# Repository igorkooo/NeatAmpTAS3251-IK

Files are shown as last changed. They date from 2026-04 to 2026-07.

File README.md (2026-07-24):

# NeatAmpTAS3251 — 2×170W Class D Amplifier with I2S Input & DSP

> ⚠️ **Hobby project** — no deadlines, no warranties, no guarantees. Use at your own risk.

<p align="center">

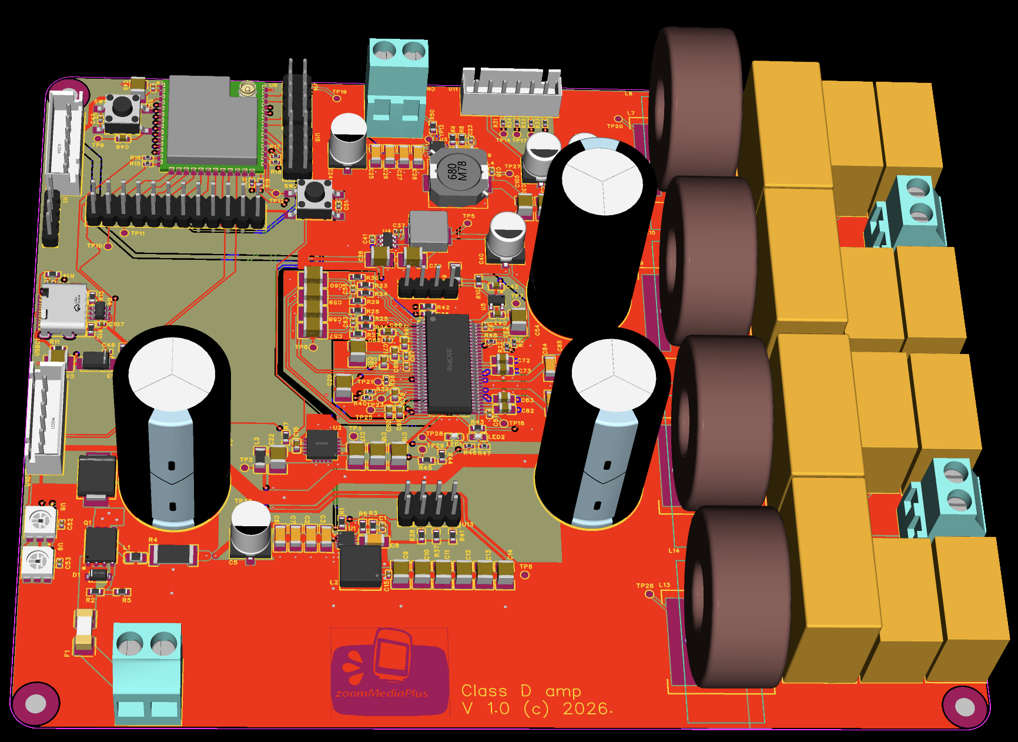
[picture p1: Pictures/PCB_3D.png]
  

</p>

2×170 W Class-D amplifier based on the Texas Instruments TAS3251, featuring an ESP32-S3 controller, DSP-ready architecture, USB-C programming, and a low-noise multi-rail power supply.

---

## Overview

This project builds on the excellent [NeatAmpTAS3251](https://github.com/jmf13/NeatAmpTAS3251/tree/master)
design by jmf13 and extends it with:

- **ESP32-S3** — WiFi control, I2C management of TAS3251 (volume, EQ, fault monitoring)
- **Output inductors** — dual footprint for Coilcraft XGL1712-103MED and Würth 7443631000
  for comparative distortion testing
- **ADAU1466 DSP ready** — I2S input connector, power supply, and I2C interface prepared
  for future DSP integration
- **Revised power supply** — fully redesigned for lower noise and better thermal performance
- **EasyEDA Pro** — migrated from KiCad v9 for simplified JLCPCB prototyping workflow

The complete hardware schematic is available in [Schematic.pdf](Schematic.pdf).

---

## Release Notes

### Version 1.1
- **Important fix** — ESP32 USB-C connector was rotated 180° in V1.0, making the
  connector unusable when assembled. Now fixed.
- Added complete JLCPCB production specifications (see
  [Production Details](#production-details-jlcpcb)) as used for the first
  prototype batch.

### Version 1.0
- PCB routing completed for the first prototype revision.
- EasyEDA Pro project migrated to the new `.eprj2` project format.
- Development performed using **EasyEDA Pro V3.2.149**.
- Latest layout improvements include routing optimisation, power distribution refinement, grounding improvements, and thermal optimisation.

---

## Status

**Version:** 1.0 (Prototype)

⚠️ This is the first public prototype release. The hardware has **not yet been validated in real-world operation**. It should be considered experimental until prototype testing is completed.

---

## Power Supply Architecture

The power supply is a multi-rail design optimised for low noise on sensitive analog paths
while keeping thermal dissipation manageable across all operating conditions.

### Rail Overview

| Rail | Voltage | Chip | Purpose |
|---|---|---|---|
| PVDD | 36V | External PSU | TAS3251 output stage (H-bridges) |
| 13.2V | Buck | LMQ66410 | Intermediate rail for GVDD chain |
| 12V GVDD | LDO | TPS7A4701 | TAS3251 gate drive (GVDD_A, GVDD_B, VDD) |
| 5V | Buck | LMQ66430 | System 5V bus, USB-C OR node |
| 3.3V digital | Buck | AP63203 | ESP32-S3, STM32, ADAU1466, TAS DAC_DVDD |
| 3.3V analog | LDO | TPS7A2033 | TAS3251 DAC_AVDD only |

### 12V GVDD Chain — LMQ66410 → TPS7A4701

The gate drive supply uses a two-stage approach: a switching regulator handles the large
36V→13.2V step efficiently, followed by a low-noise LDO for the final 13.2V→12V drop. ESP32 senses GOOD_13.2V on IO39 and once stable, it triggers 12V analog power via IO38.

```
PVDD (36V) → LMQ66410 (buck, 1.25MHz) → 13.2V → TPS7A4701 (LDO) → 12V GVDD
```

- **LMQ66410**: 36V input, 1.25MHz switching frequency (RT = 39.2kΩ), feedback
  R_FBT = 49.9kΩ / R_FBB = 4.12kΩ
- **TPS7A4701**: 1A LDO, 4µVrms noise, 82dB PSRR @ 100Hz, output set via ANY-OUT
  pin programming to 12.0V (pins 0P2V + 0P8V + 3P2V + 6P4V1 → GND)
- A ferrite bead (BLM31PG121SN1L) is placed between the 13.2V rail and TPS7A4701
  input for additional HF noise isolation

> **Why two stages?** A direct linear regulator from 36V to 12V at even 50mA load
> would dissipate ~1.2W in a small SMD package. The buck + LDO combination keeps
> total dissipation under 0.8W while achieving better noise performance than a
> single-stage buck alone.

### 5V Rail — LMQ66430

```
PVDD (36V) → LMQ66430 (buck, 1.25MHz) → 5V
```

- Feedback: R_FBT = 49.9kΩ / R_FBB = 24.9kΩ
- Feeds the 5V OR node (see USB-C section)
- Sources the 3.3V digital buck and 3.3V analog LDO

### 3.3V Digital Rail — AP63203

```
5V OR rail → AP63203 (fixed 3.3V buck) → 3.3V digital
```

- Fixed 3.3V output — no external feedback resistors
- Powers: ESP32-S3, STM32F030, ADAU1466 digital, TAS3251 DAC_DVDD
- Starts automatically on power-up (EN tied to VIN)
- Output: 2× 10µF ceramic + 1× 47µF electrolytic

### 3.3V Analog Rail — TPS7A2033

```
5V OR rail → TPS7A2033 (LDO) → 3.3VA
```

- Ultra-low noise LDO: 7µVrms, 95dB PSRR
- Feeds **only** TAS3251 DAC_AVDD — kept isolated from noisy digital loads
- Enabled by default via 100kΩ pull-up to 3.3V digital; ESP32-S3 can disable via
  ENABLE_3.3V GPIO IO40 for controlled power sequencing
- Input/output decoupling: 1µF Samsung CL10B105KB8NQNC (C5199872) on both pins

### USB-C Power OR

The board supports powering the digital section from either the main 36V supply
or a USB-C connection, enabling ESP32-S3 programming without the main supply present.

```
PVDD (36V) → LMQ66430 → 5V → Schottky D1 ─┐
                                             ├─ 5V OR rail → AP63203 → 3.3V digital
USB-C VBUS (5V) ────────→ 1N5819 D2 ────────┘
```

- When 36V is present: LMQ66430 supplies the 5V OR rail; USB-C Schottky is
  reverse-biased
- When USB-C only (programming mode): USB VBUS supplies 3.3V digital via AP63203;
  TAS3251 analog section remains unpowered
- 1MΩ discharge resistor on VBUS for clean hot-plug behaviour

---

## Microcontroller — ESP32-S3 controlling TAS3251

The ESP32-S3-WROOM-1U-N8 acts as the system controller, handling WiFi connectivity,
TAS3251 configuration, real-time monitoring, and user interface.

For the ESP32-S3 firmware workspace, including the Python environment, ESP-IDF
6.0.2 setup, build commands, and editor configuration, see the
[ESP32-S3 firmware README](tas/README.md) before continuing with the hardware
interface details below.

### Interface to TAS3251

All TAS3251 runtime control is via I2C (400kHz Fast Mode). The I2C bus is shared
with the ADAU1466 when fitted.

| Signal | ESP32-S3 GPIO | TAS3251 Pin | Notes |
|---|---|---|---|
| SDA | GPIO IO0 | SDA (54) | 4.7kΩ pull-up to 3.3V |
| SCL | GPIO IO45 | SCL (53) | 4.7kΩ pull-up to 3.3V |
| RESET_AMP | GPIO out IO42 | /RESET_AMP (27) | Active low; 10kΩ pull-up to 3.3V (default: not in reset) |
| DAC_MUTE | GPIO out IO1 | DAC_MUTE (45) | Active low; 10kΩ pull-down to GND (default: muted at boot) |
| /FAULT | GPIO in + IRQ IO41 | /FAULT (28) | Open-drain; 10kΩ pull-up; falling-edge interrupt |
| /CLIP_OTW | GPIO in + IRQ IO2 | /CLIP_OTW (29) | Open-drain; 10kΩ pull-up; falling-edge interrupt |

### TAS3251 I2C Address

Set by ADR pin (46):
- ADR → GND: address **0x90**
- ADR → 3.3V: address **0x92**

This pin is connected to ESP32 IO12.

### Switching Frequency Select — U13

The TAS3251 PWM switching frequency is set by a resistor from FREQ_ADJ (pin 18)
to AGND, broken out on jumper header **U13** (2x4, 2.54mm). Bridge exactly one
pin pair with a shunt; the current default is **pins 3-4 (10kΩ)**, giving the
highest switching frequency.

| U13 pins | R to AGND | Switching frequency |
|---|---|---|
| 3-4 | 10kΩ only | 768kHz ← highest (default) |
| 5-6 | 20kΩ only | 576kHz |
| 7-8 | 30kΩ only | 384kHz |
| 1-2 | Pulled to 3.3V | Target/slave mode (external sync via OSC_IOP/IOM) |

### What ESP32-S3 Controls via I2C

| Function | Register | Notes |
|---|---|---|
| Power on/off | B0-P0-R2 | Startup/shutdown sequence |
| Volume (per channel) | B0-P0-R61/R62 | 0.5dB steps, −103dB to +24dB |
| Soft mute | B0-P0-R3 | Or via DAC_MUTE pin |
| EQ / crossover biquads | Book 0x8C pages | 15× BiQuad per channel; crossover HPF/LPF |
| Safeload (atomic update) | B0x8C-P5-R7C | Write 5 coefficients then set flag = 0x01 |
| Fault status read | B0-P0-R94/R95 | OC, UV, OTE, clock error — read after /FAULT IRQ |
| Volume ramp speed | B0-P0-R64 | Controls startup/shutdown ramp to prevent pops |

### Fault Handling

Both /FAULT and /CLIP_OTW are open-drain active-low outputs wired to ESP32-S3
interrupt-capable GPIOs. Implemented in `tas::SystemController` — see the
[ESP32-S3 firmware README](tas/README.md#status-led-u8u9) for the full
state/color breakdown:

1. /FAULT asserts → falling-edge ISR fires → read B0-P0-R94/R95 for fault
   detail, re-assert DAC_MUTE, and drop both channels to a conservative low
   volume — **implemented**
2. If OTE (over-temperature): wait for thermal recovery, then toggle
   RESET_AMP to clear the latched fault before resuming — **not yet
   implemented** (tracked as a `TODO` in `SystemController::handleFault()`;
   the amp currently just stays muted at low volume until manually reset)
3. /CLIP_OTW is non-latching — current firmware logs each occurrence only
   (no mute, no volume change); revisit if sustained clipping in practice
   turns out to warrant automatic volume reduction
4. Report fault status to Home Assistant via WiFi MQTT — **not yet
   implemented** (no WiFi/MQTT in the firmware yet)

### Visual Indicators

| LED | Colour | Condition |
|-----|---|---|
| D_FAULT | Red | /FAULT asserted (hardware, no firmware needed) |
| D_CLIP | Yellow/Orange | /CLIP_OTW asserted (hardware, no firmware needed) |
| D_STATUS | 2× SK9822 (U8, U9), chained | ESP32-S3 controlled over a bit-banged 2-wire link (IO36 data / IO37 clock, not WS2812B) — see [Status LED (U8/U9)](tas/README.md#status-led-u8u9) in the firmware README for the color scheme |

Fault and clip LEDs are driven directly from the open-drain output through a 560Ω
resistor — they light up regardless of firmware state.

### Startup Sequence

```
Power applied
  → AP63203 starts → 3.3V digital available
  → ESP32-S3 boots (~150ms)
  → ESP32 initialises I2C
  → ESP32 asserts ENABLE_12V → TPS7A4701 enables → 12V GVDD available
  → TAS3251 comes out of reset (RESET_AMP released)
  → ESP32 writes TAS3251 configuration via I2C (volume, EQ, crossover)
  → ESP32 drives DAC_MUTE high → audio path unmuted
  → System ready
```

---

## I2S Audio Input

The board accepts I2S audio from either:

- **LHY Audio DIR9001 module** (SPDIF → I2S, 24-bit 96kHz) via 6-pin 2.54mm connector
- **ADAU1466 DSP board** (future) via the same I2S connector
- **ESP32-S3 directly** (for testing/streaming) via the same GPIO pins

I2S connector pinout (2.54mm, 6-pin vertical):

| Pin | Signal |
|-----|---|
| 1 | DATA (SDIN) |
| 2 | BCLK |
| 3 | LRCK |
| 4 | MCLK |
| 5 | +5V |
| 6 | GND |

27Ω series resistors are placed on all four signal lines between the connector and
TAS3251/ESP32-S3 for signal integrity and EMI reduction.

---

## Known Issues from Original Design

> As noted by the original author:
> - Silkscreen polarity for **C25, C26, C27, C28** was inverted — caps replaced with
>   non-polarised X7R ceramics in this revision, resolving the issue entirely.
> - Heatsink footprint required rework — addressed in PCB revision.

---

## Production Details (JLCPCB)

The first prototype batch (5 boards, V1.0/V1.1) was manufactured and assembled by
JLCPCB with the settings below. These are provided as a validated reference for
anyone reproducing the board.

### PCB Fabrication

| Parameter | Value |
|---|---|
| Layers | 4 |
| Base Material | FR-4, TG155 |
| Dimensions | 155.45 × 134.33 mm |
| PCB Thickness | 1.6 mm |
| PCB Color / Silkscreen | Blue / White |
| Outer Copper Weight | 2 oz |
| Inner Copper Weight | 1 oz |
| Surface Finish | ENIG, Gold Thickness 1U" |
| Via Covering | Plugged |
| Min Via Hole/Diameter | 0.3 mm / (0.4/0.45 mm) |
| Electrical Test | Flying Probe Fully Test |
| Mark on PCB | Remove Mark |
| Appearance Quality | IPC Class 2 Standard |
| Board Outline Tolerance | ±0.2 mm (Regular) |
| Delivery Format | Single PCB |
| Silkscreen Technology | Ink-jet Printing |
| Build Time | 3 days (PCB only) |
| Weight (5 pcs) | 0.89 kg |

> **Why these choices:** TG155 handles output-stage heat better than standard
> TG135. ENIG provides flat pads which significantly improves assembly yield on
> the fine-pitch QFN packages (TAS3251 VQFN-56, LMQ66430 VQFN-14, TPS7A4701
> VQFN-20). Plugged vias are required for the via-in-pad thermal grid under the
> TAS3251 exposed pad. 2 oz outer copper carries the high-current speaker output
> and PVDD paths.

### SMT Assembly

| Parameter | Value |
|---|---|
| PCBA Type | Standard |
| Assembly Side | Top Side |
| PCBA Qty | 5 |
| Edge Rails/Fiducials | Added by JLCPCB |
| Confirm Parts Placement | Yes |
| Bake Components | Yes |
| Photo Confirmation | Yes |
| Board Cleaning | Yes |
| Depanel & remove edge rails before delivery | Yes |
| Solder Paste | High temp. |
| Nitrogen Reflow Soldering | No |
| Flying Probe Test (post-assembly) | No |
| Function Test | No |
| Conformal Coating | No |
| Packaging | Antistatic bubble film |
| Panel Format | 1 × 1 |
| Build Time | 5–6 days (+4 days) |
| Product Classification | Audio Amplifiers — HS Code 851890 |
| Weight (5 assembled boards) | 2.29 kg |

> **Recommended for first runs:** *Confirm Parts Placement* and *Photo
> Confirmation* let you verify component orientation before reflow — worth it on
> any board with polarised or directional parts. *Board Cleaning* removes flux
> residue that could otherwise cause leakage currents on the high-impedance
> analog nodes (DAC_AVDD, AGND area).

### Not Assembled by JLCPCB (manual population)

The following components are excluded from the SMT order
(`Add into BOM = No` in EasyEDA) and must be hand-soldered:

- **L7–L14** — output filter inductors (Coilcraft XGL1712-103MED and
  Würth/Codaca MA5172-AE dual footprints) — order from Mouser
- **TP1–TP30** — test points (optional)

---

## Enclosure

⚠️ The supplied enclosure / 3D shell has **not passed the JLCPCB manufacturing review** and is **not recommended for fabrication** in its current state. It is included for reference only and requires redesign before production.

---

## Original Project

- Original design: [jmf13/NeatAmpTAS3251](https://github.com/jmf13/NeatAmpTAS3251/tree/master)
- License: [CC BY-SA 4.0](https://creativecommons.org/licenses/by-sa/4.0/) —
  this project inherits the same license.

---

## EasyEDA Pro Setup

**Recommended EasyEDA Pro version:** **V3.2.149**.

This repository includes a custom component library. To use it, create a symbolic
link inside your EasyEDA Pro libraries directory.

### macOS / Linux

```bash
# Navigate to your EasyEDA Pro libraries directory
cd ~/Documents/EasyEDA-Pro/libraries

# Create symlink to files from there so that app recognizes it
ln -s /path/to/git/NeatAmpTAS3251/EasyEDA-Pro/libraries/* .
```

### Windows

```cmd
:: Run Command Prompt as Administrator
cd %USERPROFILE%\EasyEDA-Pro\libraries

:: Create directory symlink
mklink /D NeatAmpTAS3251-lib C:\path\to\NeatAmpTAS3251\library
```

After creating the symlink, restart EasyEDA Pro. The library will appear in the
**Libraries** panel under `NeatAmpTAS3251-lib`.

> **Note:** Replace `/path/to/NeatAmpTAS3251/library` with the actual path where
> you cloned this repository. The EasyEDA Pro libraries directory location may vary
> by OS version — check your EasyEDA Pro installation settings if the default path
> above does not exist.

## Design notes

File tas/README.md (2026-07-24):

| Target | ESP-IDF |
| --- | --- |
| ESP32-S3 (ESP32-S3-WROOM-1U-N8R8) | 6.0.2 |

# Tas — ESP32-S3 Controller Firmware

ESP32-S3 firmware for the [NeatAmpTAS3251](../README.md) Class-D amplifier
board: a C++ class-based driver stack (see
[Firmware Architecture](#firmware-architecture) below) that sequences the
power rails, brings the TAS3251 out of reset, configures it over I2C, and
monitors /FAULT, /CLIP_OTW and the 13.2V rail — see
[ESP32-S3 Hardware IO](#esp32-s3-hardware-io) for the underlying pin map.

This firmware targets the ESP32-S3 only — the board and this project are not
built for any other Espressif chip.

## Local setup

The repository uses a local Python virtual environment for project-side Python
commands. Create it once from the project directory:

```sh
python3 -m venv .venv
source .venv/bin/activate
```

Initialize the ESP-IDF toolchain in each new shell. This sets `IDF_PATH`, adds
`idf.py` to `PATH`, and selects the ESP-IDF tools and its compatible managed
Python environment required by the build:

```sh
export IDF_PATH=~/.espressif/v6.0.2/esp-idf
source "$IDF_PATH/export.sh"
```

`~/.espressif/v6.0.2/esp-idf` is where the ESP-IDF Installation Manager
(`eim`) installs ESP-IDF 6.0.2 by default on any machine/user; adjust the
path only if you installed it somewhere else.

Run the ESP-IDF commands after `export.sh`; ESP-IDF may replace the active
`.venv` interpreter with its managed environment so all ESP-IDF dependencies
match the installed ESP-IDF release.

Select the target and build:

```sh
idf.py set-target esp32s3
idf.py build
```

The generated `build/compile_commands.json` is used by clangd and C/C++
IntelliSense. Keeping the project build configured ensures ESP-IDF headers
such as `esp_system.h` and `esp_flash.h` resolve without missing-include
warnings.

`sdkconfig.defaults` sets the flash size (8 MB) and PSRAM (8 MB Quad) to
match the ESP32-S3-WROOM-1U-N8R8 module actually used on this board. If a
fresh `sdkconfig` ever comes up as 2 MB flash / no PSRAM again (check the
boot log — see
[Chip and firmware info logging](#chip-and-firmware-info-logging) — or
`grep CONFIG_SPIRAM sdkconfig`), run `idf.py reconfigure`; if it's still
missing, confirm `esp_psram` is still in `main`'s `PRIV_REQUIRES` in
`main/CMakeLists.txt` — this project builds with `MINIMAL_BUILD ON`
(root `CMakeLists.txt`), which silently drops `CONFIG_SPIRAM` from the
Kconfig tree entirely if nothing depends on `esp_psram`.

The test dependencies are listed by `pytest_tas.py`. Install them into the
active virtual environment when PyPI access is available:

```sh
python -m pip install pytest pytest-embedded-idf pytest-embedded-qemu
python -m pytest -q pytest_tas.py
```

## Configuration (menuconfig)

The portable way to open the config menu, on any machine, once the toolchain
is exported as above:

```sh
idf.py menuconfig
```

### VSCode SDK Configuration Editor

If the ESP-IDF extension's "SDK Configuration Editor" (GUI menuconfig) does
not open, it is almost always because `.vscode/settings.json`'s
`idf.currentSetup` does not match an installation known to the ESP-IDF
Installation Manager (`eim`) on this machine. That setting must hold an
**install ID** (e.g. `esp-idf-<hash>`), not a filesystem path — a path there
looks plausible but silently fails to resolve.

To fix it on any machine after installing ESP-IDF via `eim`:

```sh
cat ~/.espressif/tools/eim_idf.json
```

Copy the `idfSelectedId` value (or the `id` of the entry matching the ESP-IDF
version you want) into `.vscode/settings.json`:

```json
"idf.currentSetup": "esp-idf-<hash-from-eim_idf.json>"
```

This ID is generated per machine by `eim`, so it will differ on every
computer — re-run this step after cloning the repo onto a new machine or
after reinstalling ESP-IDF. Reload the VSCode window afterwards.

`idf.port` in the same file is also machine-specific (the serial device path
of the connected board): `/dev/tty.usbmodem*` on macOS, `/dev/ttyUSB*` or
`/dev/ttyACM*` on Linux, `COM*` on Windows. Update it to match your board
before flashing or monitoring from VSCode.

## Debugging (OpenOCD)

The `gdbtarget` debug configuration in `.vscode/launch.json` has
`runOpenOCD` default to `true` (see the extension's `package.json`), so
**every** "Start Debugging" tries to spawn a fresh OpenOCD server. If a
previous session was force-stopped, crashed, or otherwise didn't shut its
OpenOCD process down cleanly, that old server keeps holding ports 3333
(GDB), 4444 (telnet) and 6666 (Tcl) — the new one then fails to bind them,
which is what "server already started" / can't-start-debug means.

`.vscode/launch.json`'s debug configuration now runs a `preLaunchTask`
("Reset OpenOCD", defined in `.vscode/tasks.json`) before every debug
session, which kills any leftover OpenOCD process first
(`pkill -f 'bin/openocd'` on macOS/Linux, `taskkill /IM openocd.exe` on
Windows) so the new one always gets a clean set of ports. If you ever need
to do this by hand instead: **Terminal → Run Task… → Reset OpenOCD**, or
directly:

```sh
pkill -f 'bin/openocd'    # macOS / Linux
```

### Debug launches an old binary / doesn't flash first

The `gdbtarget` `attach` config's `buildFlashMonitor` option (build, flash
and monitor before attaching) defaults to `false`. With it unset, clicking
Debug just attaches GDB via OpenOCD to **whatever is already on the
chip** — it does not build or flash your current source first. If the
serial log shown by a debug/monitor session doesn't match your code (e.g.
still shows the stock `hello_world` example, an old project name, or an old
compile timestamp in the `app_init:` banner lines — see
[Chip and firmware info logging](#chip-and-firmware-info-logging) below for
where to check that), this is almost always why: the board was never
actually reflashed with the current build, only attached to.

`.vscode/launch.json`'s debug configuration now sets `"buildFlashMonitor":
true`, so every Debug launch builds, flashes and monitors before attaching.
If you ever want to attach without reflashing (e.g. to inspect a crash
without touching the board's current state), temporarily set it back to
`false` for that session, or flash explicitly first instead:

```sh
idf.py -p PORT flash
```

## ESP32-S3 Hardware IO

The firmware pin definitions are kept in [tas_pins.h](main/tas_pins.h). GPIO
configuration and default power-up states are owned by
[PowerSupplies](main/power_supplies.cpp) and [Tas3251](main/tas3251.cpp) (see
[Firmware Architecture](#firmware-architecture)); the shared I2C master bus
(`I2C_NUM_0`, 400 kHz) is created by [I2cBus](main/i2c_bus.cpp).

| Signal | ESP32-S3 IO | Direction / interface | Purpose | Jumper needed |
|---|---|---|---|---|
| I2C SDA | IO0 | I2C data | Shared I2C data line for TAS3251 and optional ADAU1466 | No |
| I2C SCL | IO45 | I2C clock | Shared I2C clock line for TAS3251 and optional ADAU1466 | No |
| AMP RESET | IO42 | GPIO output | Releases or holds the TAS3251 in reset; active low | Yes — U14 pins 5-6 (IO42 to TAS_RESET) |
| DAC MUTE | IO1 | GPIO output | Hardware mute control for the TAS3251; active low | Yes — U14 pins 1-2 (IO1 to TAS_MUTE) |
| AMP FAULT | IO41 | GPIO input / interrupt | Receives latched TAS3251 fault indications | Yes — U14 pins 7-8 (IO41 to TAS_FAULT) |
| AMP CLIP/OTW | IO2 | GPIO input / interrupt | Receives clipping or over-temperature warning indications | Yes — U14 pins 3-4 (IO2 to TAS_CLIP) |
| AMP ADDRESS | IO12 | GPIO input | Reads the TAS3251 ADR strap state for I2C address selection | Yes — H2 pins 13-14 (TAS_ADR to ESP_TAS_ADR) |
| GOOD 13.2V | IO39 | GPIO input | Confirms that the 13.2 V intermediate rail is ready through jumper U15 | Yes — U15 pins 5-6 (IO39 to GOOD_13.2V) |
| ENABLE 12V | IO38 | GPIO output | Enables the 12 V GVDD analog supply after 13.2 V is good through jumper U15 | Yes — U15 pins 7-8 (IO38 to ENABLE_12V) |
| ENABLE 3.3V analog | IO40 | GPIO output | Enables the isolated 3.3 V analog rail for TAS3251 DAC_AVDD | Yes — U15 pins 3-4 (IO40 to ENABLE_3.3V) |

Header U14 (2x4, 2.54 mm) carries the amplifier control/status lines between
the ESP32-S3 and the TAS3251, and header U15 (2x4, 2.54 mm) carries the power
sequencing lines between the ESP32-S3 and the rail-good/enable signals; on
both, each ESP32-S3 GPIO net and its counterpart signal are broken out to
adjacent pins in the same column so that a 2-pin shunt bridges them. Header
H2 (2x12) is the main board-to-board connector, and only its pins 13-14 need
a jumper to route the TAS3251 ADR strap to the ESP32-S3. None of these
headers ship with shunts populated by default, so populate the pin pairs
above per the current firmware pin mapping in [tas_pins.h](main/tas_pins.h)
before relying on these signals; per the netlist
(`Netlist_Class_D_amp_2026-07-23.enet` at the repository root), leaving a
pair open floats that signal instead of connecting it.

At GPIO configuration time (`Tas3251::init()`), RESET_AMP and DAC_MUTE are
driven to their safe defaults — reset asserted, muted — and both the 12 V and
3.3 V analog rails start disabled; `SystemController::startup()` then runs
the sequence in [Firmware Architecture](#firmware-architecture) to bring
everything up in order. The I2C lines rely on the board-level 4.7 kOhm
pull-ups.

## Potential DSP (ADAU1466) Connectivity

The board breaks out a DSP interface on connector U10 (1x6, 2.54 mm) for a
future ADAU1466 DSP module. RESET and SELFBOOT are direct GPIO connections;
the I2C lines join the shared TAS3251 bus through 22 Ohm series resistors
rather than a separate bus.

| Signal | ESP32-S3 IO | U10 pin | Direction / interface | Purpose | Jumper needed |
|---|---|---|---|---|---|
| DSP_RESET | IO47 | 3 | GPIO output | Resets the ADAU1466 DSP | No |
| DSP_SELFBOOT | IO48 | 6 | GPIO output | Sets the ADAU1466 self-boot mode strap | No |
| DSP SDA | IO0 | 4 | I2C data | Joins the shared I2C data line via 22 Ohm series resistor R19 | No |
| DSP SCL | IO45 | 5 | I2C clock | Joins the shared I2C clock line via 22 Ohm series resistor R20 | No |

U10 pins 1 and 2 carry GND and 3.3V respectively for powering the DSP module.

## Firmware Architecture

The firmware is C++ (`gnu++26`, exceptions and RTTI disabled per
`sdkconfig`, matching the rest of ESP-IDF). Each hardware concern is owned by
one class; `tas_pins.h` remains the single source of truth for GPIO numbers.

| Class | Files | Owns |
|---|---|---|
| `tas::I2cBus` | [i2c_bus.hpp](main/i2c_bus.hpp) / [.cpp](main/i2c_bus.cpp) | The shared I2C master bus (SDA/SCL), device attach/probe |
| `tas::Tas3251` | [tas3251.hpp](main/tas3251.hpp) / [.cpp](main/tas3251.cpp) | RESET_AMP, DAC_MUTE, /FAULT + /CLIP_OTW IRQs, AMP ADDRESS strap, book/page I2C register access |
| `tas::Dsp` | [dsp_adau1466.hpp](main/dsp_adau1466.hpp) / [.cpp](main/dsp_adau1466.cpp) | DSP_RESET, DSP_SELFBOOT, I2C presence probe for the optional ADAU1466 |
| `tas::PowerSupplies` | [power_supplies.hpp](main/power_supplies.hpp) / [.cpp](main/power_supplies.cpp) | GOOD_13.2V sense, ENABLE_12V, ENABLE_3.3V analog |
| `tas::I2sBus` | [i2s_bus.hpp](main/i2s_bus.hpp) / [.cpp](main/i2s_bus.cpp) | ESP-IDF I2S std-mode TX channel for the shared TAS3251/DSP audio bus |
| `tas::StatusLed` | [status_led.hpp](main/status_led.hpp) / [.cpp](main/status_led.cpp) | Bit-banged SK9822 (APA102-compatible) driver for the U8/U9 status LED chain |
| `tas::SystemController` | [system_controller.hpp](main/system_controller.hpp) / [.cpp](main/system_controller.cpp) | Startup sequencing, fault/clip handling, and the steady-state monitor loop, composing the classes above |

`main/tas_main.cpp` (`app_main`) only constructs a `SystemController` and
calls `startup()` then `runForever()`.

⚠️ **`I2sPins` in `i2s_bus.hpp` has no wired GPIOs on the current board.**
Per `Netlist_Class_D_amp_2026-07-23.enet` (repository root), connector U11
(MCLK/LRCK/SCLK/SDIN) only reaches the TAS3251 — the ESP32-S3 has no *PCB*
net in common with the I2S bus on this revision, despite the top-level
README's "ESP32-S3 directly (for testing/streaming)" bullet. `I2sBus` is a
working scaffold for a future revision (or rework) that does wire it up; it
isn't used by `SystemController` yet. See
[I2S Test Tone (H2-to-U11 Patch)](#i2s-test-tone-h2-to-u11-patch) below for a
way to exercise it today with a manual patch instead of a board respin.

### Startup sequence

`SystemController::startup()` runs the following states, logging each
transition at `ESP_LOGI` and any failure at `ESP_LOGE` (aborting the sequence
on failure, leaving the amplifier held in reset and muted):

```
INIT                    → status LED (blue), I2C bus, GPIOs, /FAULT + /CLIP_OTW IRQs, DSP probe
AMP_RESET               → RESET_AMP asserted, DAC_MUTE asserted
WAIT_POWER_STABLE       → 100 ms delay (see ⚠️ below)
CHECK_13V2              → poll GOOD_13.2V; abort if not good
ENABLE_12V              → enable the 12V GVDD analog rail
ENABLE_3V3_ANALOG       → enable the 3.3V analog (DAC_AVDD) rail
WAIT_PRE_RESET_RELEASE  → 50 ms delay (see ⚠️ below)
RELEASE_RESET           → RESET_AMP released
CONFIGURE               → power on (B0-P0-R2), set a conservative low startup volume
UNMUTE                  → DAC_MUTE released
READY                   → status LED (green), hand off to runForever()
```

Any failure along the way aborts the sequence, sets `SystemController::status()`
to `StartupFailed`, and turns the status LED amber (see
[Status LED (U8/U9)](#status-led-u8u9) below) — the amplifier stays held in
reset and muted.

`SystemController::runForever()` then polls `/FAULT`, `/CLIP_OTW` and
GOOD_13.2V every 50 ms, logging state changes and reacting to `/FAULT` and
`/CLIP_OTW` as described in [Status LED (U8/U9)](#status-led-u8u9).

⚠️ **Open questions carried over from architecture review, marked `TODO` in
the code (`system_controller.cpp`, `tas3251.hpp`) — verify against the actual
TAS3251 datasheet before trusting them in the field:**

- The 100 ms `WAIT_POWER_STABLE` and 50 ms `WAIT_PRE_RESET_RELEASE` delays
  are placeholders, not datasheet-derived timings. If `GOOD_13.2V` already
  guarantees the rails have settled, the first delay may be unnecessary; the
  second should be checked against the TAS3251's minimum reset/supply
  sequencing spec.
- Whether the 3.3V analog (AVDD) rail must be enabled a fixed time
  before/after the 12V (GVDD) rail, rather than immediately after it as
  implemented, is unconfirmed.
- `Tas3251::powerOn()`'s DEVICE_CTRL_2 (B0-P0-R2) bit encoding and
  `Tas3251::setVolumeDb()`'s dB-to-register-code formula both follow common
  TI PurePath conventions but are **unverified for TAS3251 specifically**.
  The startup sequence deliberately uses a conservative low volume
  regardless, so a wrong-but-quiet result is the worst case today — confirm
  both against the datasheet before writing arbitrary volumes in the field.
- `Dsp`'s placeholder I2C address (`0x38`) is unconfirmed; harmless today
  since no board has the ADAU1466 populated.

### Status LED (U8/U9)

U8 and U9 are SK9822 (APA102-compatible) addressable RGB LEDs, chained in
series and driven from the ESP32-S3 over a bit-banged two-wire link:
IO36 → 27 Ω → `L_SDI` (data, into U8) and IO37 → 27 Ω → `L_CKI` (clock); U8's
CKO/SDO feed U9's CKI/SDI. This is **not** a WS2812B (single-wire) — see the
correction in the top-level [README.md](../README.md#visual-indicators).
`tas::StatusLed` treats the chain as two independently-addressable LEDs and
gives them different jobs:

- **LED 0 (U8) — persistent `SystemController::Status`:**

  | Status | Color | Meaning |
  |--------|-------|---------|
  | `Booting` | Blue | `startup()` is running |
  | `Ready` | Green | Startup succeeded; amp unmuted, nominal volume |
  | `Fault` | Red | `/FAULT` latched; amp muted at low volume (see below) |
  | `StartupFailed` | Amber | `startup()` aborted before reaching `Ready` |

- **LED 1 (U9) — transient `/CLIP_OTW` indicator:** off normally; flashes
  amber for ~120 ms each time `/CLIP_OTW` fires, then returns to off. Purely
  a visual cue — it does not reflect or change `Status`.

**Fault vs. clip handling** (`SystemController::handleFault()` /
`handleClipOtw()`, called from `runForever()`):

- **`/FAULT`**: logs the latched fault bytes (B0-P0-R94/R95), re-asserts
  `DAC_MUTE` and sets both channels to the same conservative low volume used
  at startup, sets `Status` to `Fault` (LED 0 red), and **stays there** —
  there's no automatic recovery yet (see the `TODO` in
  `SystemController::handleFault()` and the existing "Fault Handling"
  section in the top-level README for the intended recovery policy: wait for
  thermal recovery, then toggle `RESET_AMP`).
- **`/CLIP_OTW`**: logs only (`ESP_LOGW`) and flashes LED 1 — no mute, no
  volume change, no `Status` change. This is a deliberate design choice:
  clipping is common/non-latching and shouldn't itself silence the amp,
  unlike a real `/FAULT`.

### Chip and firmware info logging

Before the `INIT` state, `startup()` logs everything readily available about
the running chip and firmware image at `ESP_LOGI`: target/core
count/silicon revision/radio features, flash size and type, WiFi-STA MAC
address, current and minimum-ever free heap, the firmware's project
name/version/build timestamp/ESP-IDF version (from `esp_app_get_description()`,
i.e. this project's actual name/version, not a stale one), and the reason
for the last reset (power-on, software, watchdog, brownout, etc.). This is
the first thing to check in a serial capture — the project name and compile
timestamp there is the ground truth for what's actually running on the
board, e.g. if it still says `hello_world` instead of `tas`, the board was
never flashed with this project's build; see
[Debug launches an old binary / doesn't flash first](#debug-launches-an-old-binary--doesnt-flash-first)
above.

### Generating documentation

All classes are commented for Doxygen (`@file`/`@brief`/`@param`/`@return`/
`@note`/`@warning`). Generate HTML docs from the `tas/` directory:

```sh
doxygen Doxyfile
open docs/html/index.html
```

## I2S Test Tone (H2-to-U11 Patch)

**Status: proposed / not yet implemented in firmware.** This is a bring-up
idea for exercising the audio path without a board respin, recorded here
before writing the code.

Connector H2 (2x12, the main board-to-board header) breaks out several
ESP32-S3 GPIOs that this firmware does not otherwise use. Checked against
`Netlist_Class_D_amp_2026-07-23.enet`, the following H2 pins are genuinely
spare (not assigned to any signal in [ESP32-S3 Hardware IO](#esp32-s3-hardware-io)
or [Potential DSP (ADAU1466) Connectivity](#potential-dsp-adau1466-connectivity)):

| H2 pin | ESP32-S3 IO | Notes |
|---|---|---|
| 16 | IO13 | free |
| 18 | IO14 | free |
| 20 | IO21 | free |
| 4 | IO3 | free, but an ESP32-S3 strapping pin (JTAG source select) — avoid |
| 6 | IO46 | free, but an ESP32-S3 strapping pin (ROM print control) — avoid |
| 7 | IO8 | free |
| 8 | IO9 | free |
| 10 | IO10 | free |
| 12 | IO11 | free |

Since connector U11 (the I2S input header, see
[Firmware Architecture](#firmware-architecture) above) only reaches the
TAS3251 and nothing else drives it, a user-installed patch from three of the
free H2 pins to U11 lets the ESP32-S3 act as a temporary I2S source for the
amplifier — no board respin needed:

| U11 pin | Signal | Patch to H2 pin | ESP32-S3 IO |
|---|---|---|---|
| 4 | LRCK (WS) | 18 | IO14 |
| 5 | SCLK (BCLK) | 16 | IO13 |
| 6 | SDIN (DOUT, ESP32 → TAS3251) | 20 | IO21 |
| 3 | MCLK | *TBD* | — |
| 1 | GND | any H2 GND pin (15/17/19/21-24) | — |

MCLK is left open for now: it's unconfirmed whether the TAS3251's I2S input
requires an external MCLK or can derive its clock from BCLK/LRCK alone
(`I2sBus`/`i2s_std` do support MCLK-less operation). If bring-up shows MCLK
is required, H2 pin 7 (IO8), 8 (IO9), 10 (IO10) or 12 (IO11) are the next
free candidates — avoid IO3/IO46 (H2 pins 4/6) since they're ESP32-S3
strapping pins.

⚠️ **Do not patch H2 to U11 while a DIR9001 module (or anything else) is also
connected to U11** — the ESP32-S3 would then be driving LRCK/SCLK/SDIN into
whatever else is driving those same lines.

### Planned firmware behavior

Once implemented: 5 seconds after `SystemController::startup()` reaches the
`READY` state (i.e. after the amplifier is configured and unmuted), the
firmware logs a new state (e.g. `TEST_TONE_START`) and starts writing a
continuous 1 kHz sine wave to both channels via `I2sBus::writeSamples()` —
same 16-bit/48 kHz stereo interleaved format `I2sBus` already assumes. This
would likely live in a small new class (e.g. `TestToneGenerator`) that owns
the sample buffer and reuses `I2sBus` rather than being folded into
`SystemController` directly, so it can be compiled out entirely once no
longer needed for bring-up.

## Project folder contents

```
├── CMakeLists.txt
├── Doxyfile                     Doxygen config (see Generating documentation above)
├── sdkconfig                    Board-specific build configuration (see Configuration above)
├── pytest_tas.py                 Automated test entry point
├── main
│   ├── CMakeLists.txt
│   ├── tas_main.cpp               App entry point (app_main)
│   ├── tas_pins.h                 GPIO/I2C pin definitions, single source of truth
│   ├── i2c_bus.hpp / .cpp          tas::I2cBus
│   ├── tas3251.hpp / .cpp          tas::Tas3251
│   ├── dsp_adau1466.hpp / .cpp     tas::Dsp
│   ├── power_supplies.hpp / .cpp   tas::PowerSupplies
│   ├── i2s_bus.hpp / .cpp          tas::I2sBus
│   └── system_controller.hpp / .cpp  tas::SystemController
└── README.md
```

## Troubleshooting

* Program upload failure

    * Hardware connection is not correct: run `idf.py -p PORT monitor`, and reboot your board to see if there are any output logs.
    * The baud rate for downloading is too high: lower your baud rate via [Configuration (menuconfig)](#configuration-menuconfig), and try again.

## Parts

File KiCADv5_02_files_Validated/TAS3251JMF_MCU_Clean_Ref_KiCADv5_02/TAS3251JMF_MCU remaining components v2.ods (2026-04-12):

Ref | Qnty | Value | Cmp name | Mouser ref | Unit cost | Footprint | Description
U1, | 1 | TAS3251 | TAS3251DKQR | 595-TAS3251DKQR | 9,89 | TAS3251:DKQ0056A
HS1, | 1 | Heatsink | Heatsink_Pad | 984-ATI1OP1099C1R1 | 9,2 | TAS3251:Advanced_ATS078036036-TI1OP-1099-C1-R1 | https://www.digikey.com/product-detail/en/advanced-thermal-solutions-inc/ATS-TI1OP-519-C1-R3/ATS2180-ND/5125225
C15, C16, | 2 | 2400µF | EEU-FC1H222 | 667-EEU-FC1H222 | 1,88 | Capacitor_THT:CP_Radial_D18.0mm_P7.50mm
C29, C30, C31, C32, | 4 | 0.68µF | B32652A3684J | 871-B32652A3684J | 0,891 | Capacitor_THT:C_Rect_L18.0mm_W9.0mm_P15.00mm_FKS3_FKP3
L5, | 1 | 150µH | #74404064151 | 710-74404064151 | 1,12 | TAS3251:L_Wuerth_74404064151_Handsolder | Inductor
C25, C26, C27, C28, | 4 | 10ÂµF | RFS-16V100ME3#5 | 555-RFS16V100ME3#5 | 0,27 | Capacitor_THT:CP_Radial_D5.0mm_P2.00mm
R19 | 1 | 365k |  | 71-CRCW0805-365K-E3 | 0,09 | 805
R3 | 1 | 22k |  | 71-CRCW080522K6FKEAC | 0,144 | 805
C5, C49 | 2 | 0.1uF |  | 80-C0805X104K5R3316 | 0,297 | 0805 X7R
C50 | 1 | 4700pF |  | 80-C0805C472K5R | 0,09 | 0805 X7R
C22 | 1 | 0.047uF |  | 603-CC805KRX7R9BB473 | 0,135 | 0805 X7R
C8 | 1 | 1uF |  | 81-GCM21BR71H105KA3L | 0,279 | 0805 X7R
C42 | 1 | 100uF |  | 667-EEE-FK0J101UR | 0,369 | CP_Elec_5x5.8 xxSMD-ECAP-5x5.3 - xCAP,AL, 100 ?F, 6.3 V, +/- 20%,0.7ohm,SMD
L3, L4, L1, L2, | 4 | 10 µH | #7443631000 | 710-7443631000 | 6,3 | SamacSys_Parts:WE-HCF_201322
Done
J3, J4, J5 | 3 | OUTA | CMP-0075104-1 |  | 1,77 | TerminalBlock_Phoenix:TerminalBlock_Phoenix_MKDS-3-2-5.08_1x02_P5.08mm_Horizontal
J12, | 1 | Conn_02x03_Odd_Even | Conn_02x03_Odd_Even |  |  | Connector_IDC:IDC-Header_2x03_P2.54mm_Vertical | Generic connector, double row, 02x03, odd/even pin numbering scheme (row 1 odd numbers, row 2 even numbers), script generated (kicad-library-utils/schlib/autogen/connector/)
J1, | 1 | Oscill sync | 22112042 |  |  | Connector_Molex:Molex_KK-254_AE-6410-04A_1x04_P2.54mm_Vertical
J2, | 1 | Freq Adjust | PEC04DAAN |  |  | Connector_PinHeader_2.54mm:PinHeader_2x04_P2.54mm_Vertical
J11, J15, | 2 | Conn_01x06 | Conn_01x06 |  |  | Connector_PinHeader_2.54mm:PinHeader_1x06_P2.54mm_Vertical | Generic connector, single row, 01x06, script generated (kicad-library-utils/schlib/autogen/connector/)
J13, J19, J18, | 3 | Conn_01x04 | Conn_01x04 |  |  | Connector_PinHeader_2.54mm:PinHeader_1x04_P2.54mm_Vertical | Generic connector, single row, 01x04, script generated (kicad-library-utils/schlib/autogen/connector/)
J16, | 1 | Conn_01x03 | Conn_01x03 |  |  | Connector_PinHeader_2.54mm:PinHeader_1x03_P2.54mm_Vertical | Generic connector, single row, 01x03, script generated (kicad-library-utils/schlib/autogen/connector/)
J17, | 1 | Conn_01x10 | Conn_01x10 |  |  | Connector_PinHeader_2.54mm:PinHeader_1x10_P2.54mm_Vertical | Generic connector, single row, 01x10, script generated (kicad-library-utils/schlib/autogen/connector/)
JP1, | 1 | AMP RESET Jumper | Jumper_3_Bridged12 |  |  | Connector_PinHeader_2.54mm:PinHeader_1x03_P2.54mm_Vertical | Jumper, 3-pole, pins 1+2 closed/bridged
JP2, JP3, JP4, JP5, | 4 | Jumper_2_Bridged | Jumper_2_Bridged |  |  | Connector_PinHeader_2.54mm:PinHeader_1x02_P2.54mm_Vertical | Jumper, 2-pole, closed/bridged

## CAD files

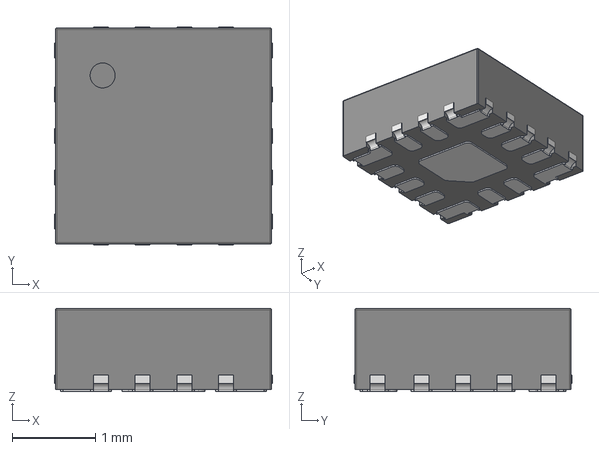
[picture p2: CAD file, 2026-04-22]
KiCADv5_02_files_Validated/LMQ66430R5RXBR.stp
2.62 x 2.62 x 1.00 mm

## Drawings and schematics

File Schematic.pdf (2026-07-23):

3.3V

## GOOD_13.2V

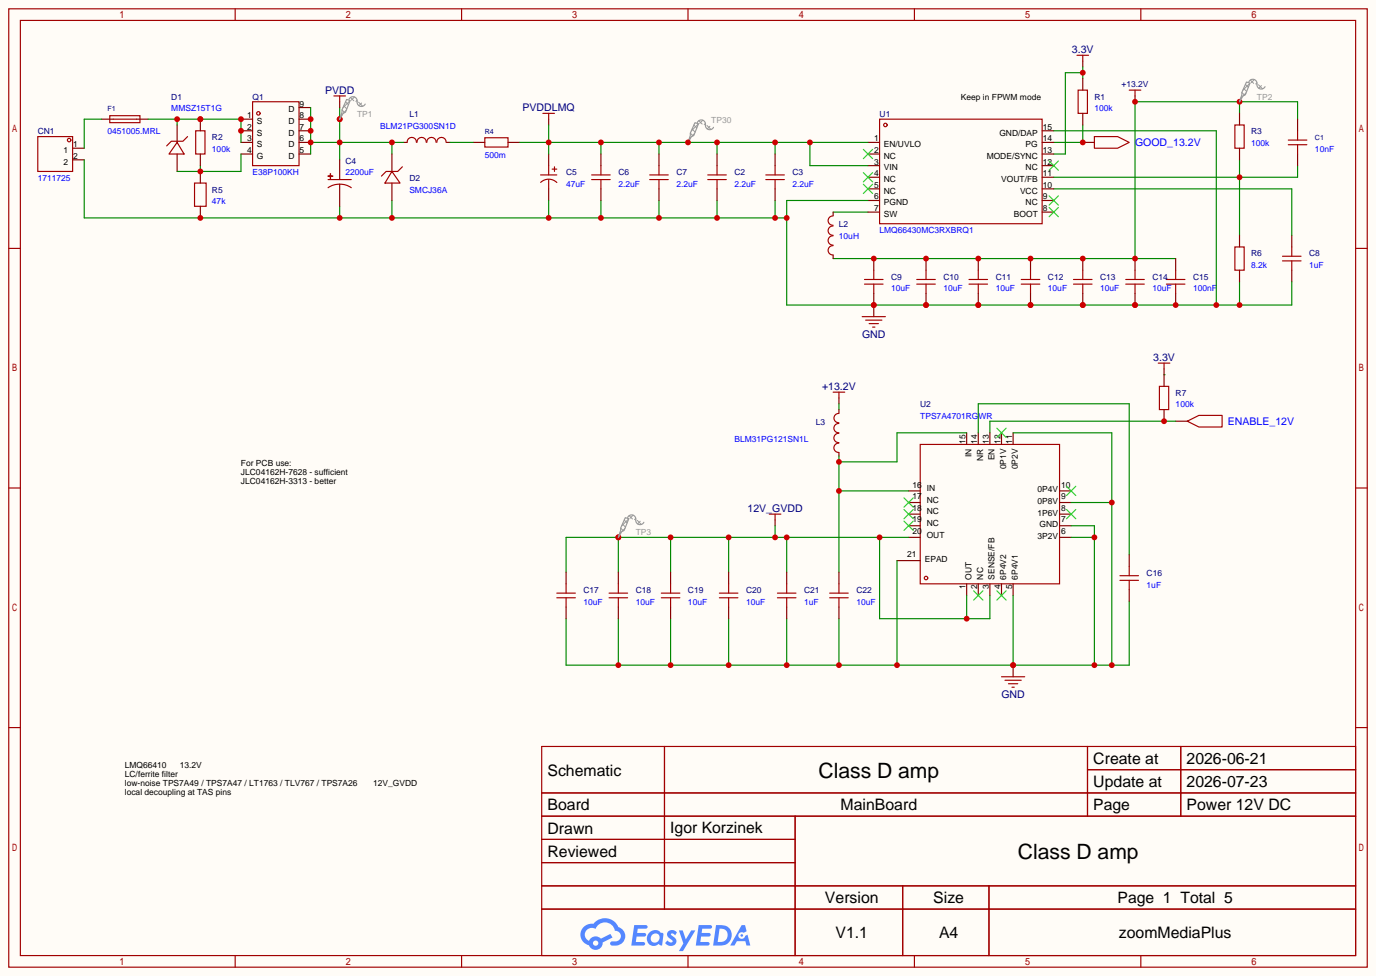
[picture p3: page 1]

Keep in FPWM mode

Schematic | Class D amp | Create at | 2026-06-21

LMQ66410 13.2V
LC/ferrite filter
local decoupling at TAS pins

Update at | 2026-07-23

Board | MainBoard | Page | Power 12V DC
Drawn | Igor Korzinek | Class D amp
Reviewed

Version | Size | Page 1 Total 5
V1.1 | A4 | zoomMediaPlus

PVDDLMQ | TP13

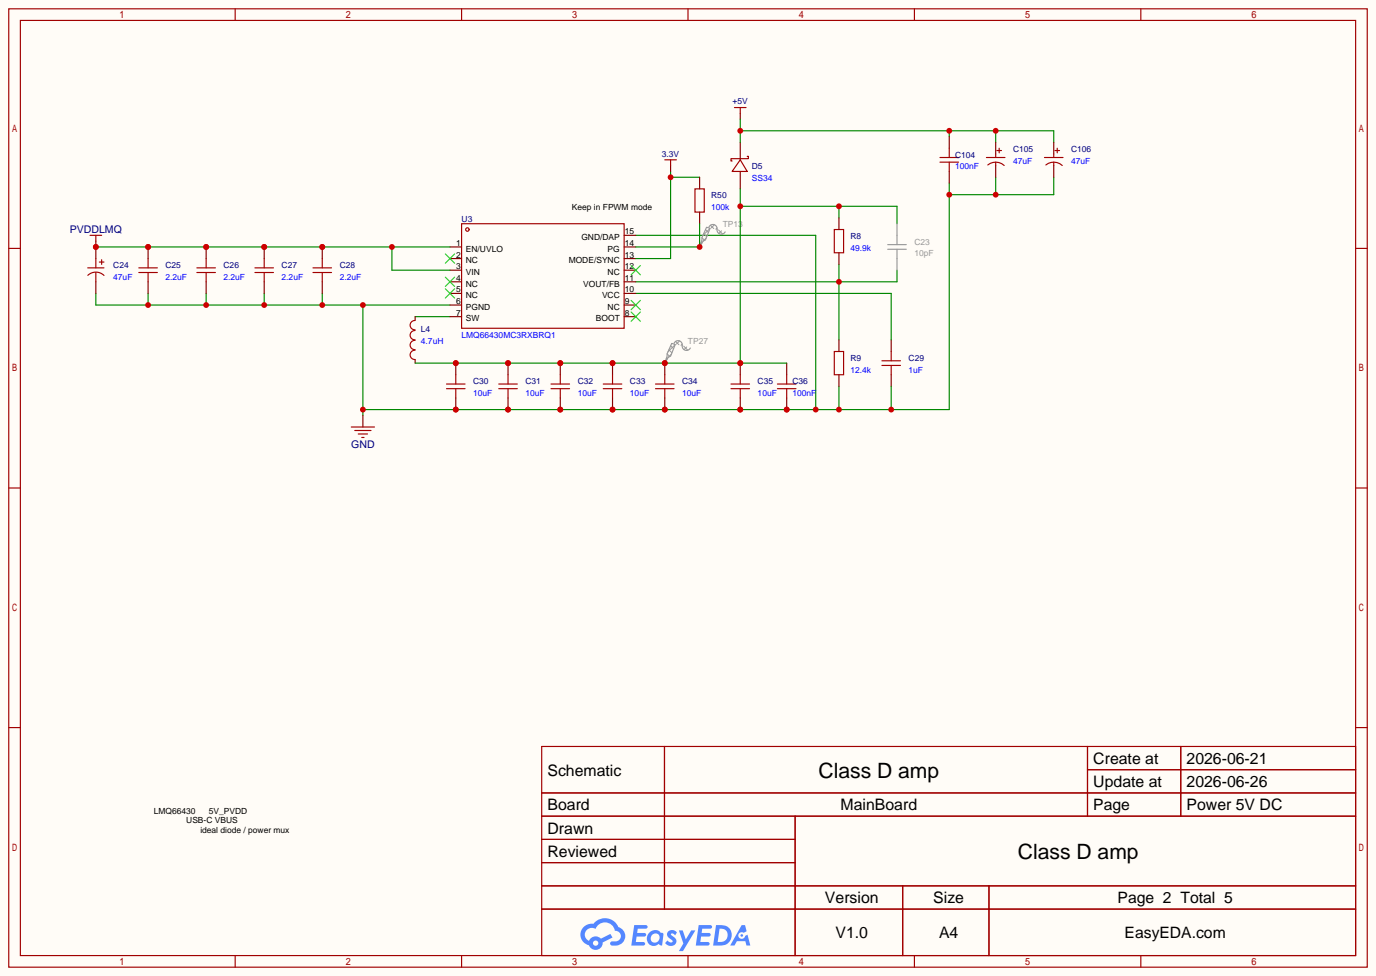
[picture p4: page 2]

Keep in FPWM mode

Schematic | Class D amp | Create at | 2026-06-21

Update at | 2026-06-26

Board | MainBoard | Page | Power 5V DC
Drawn | | Class D amp
Reviewed

LMQ66430 5V_PVDD
└── USB-C VBUS
└── ideal diode / power mux

Version | Size | Page 2 Total 5
V1.0 | A4 | EasyEDA.com

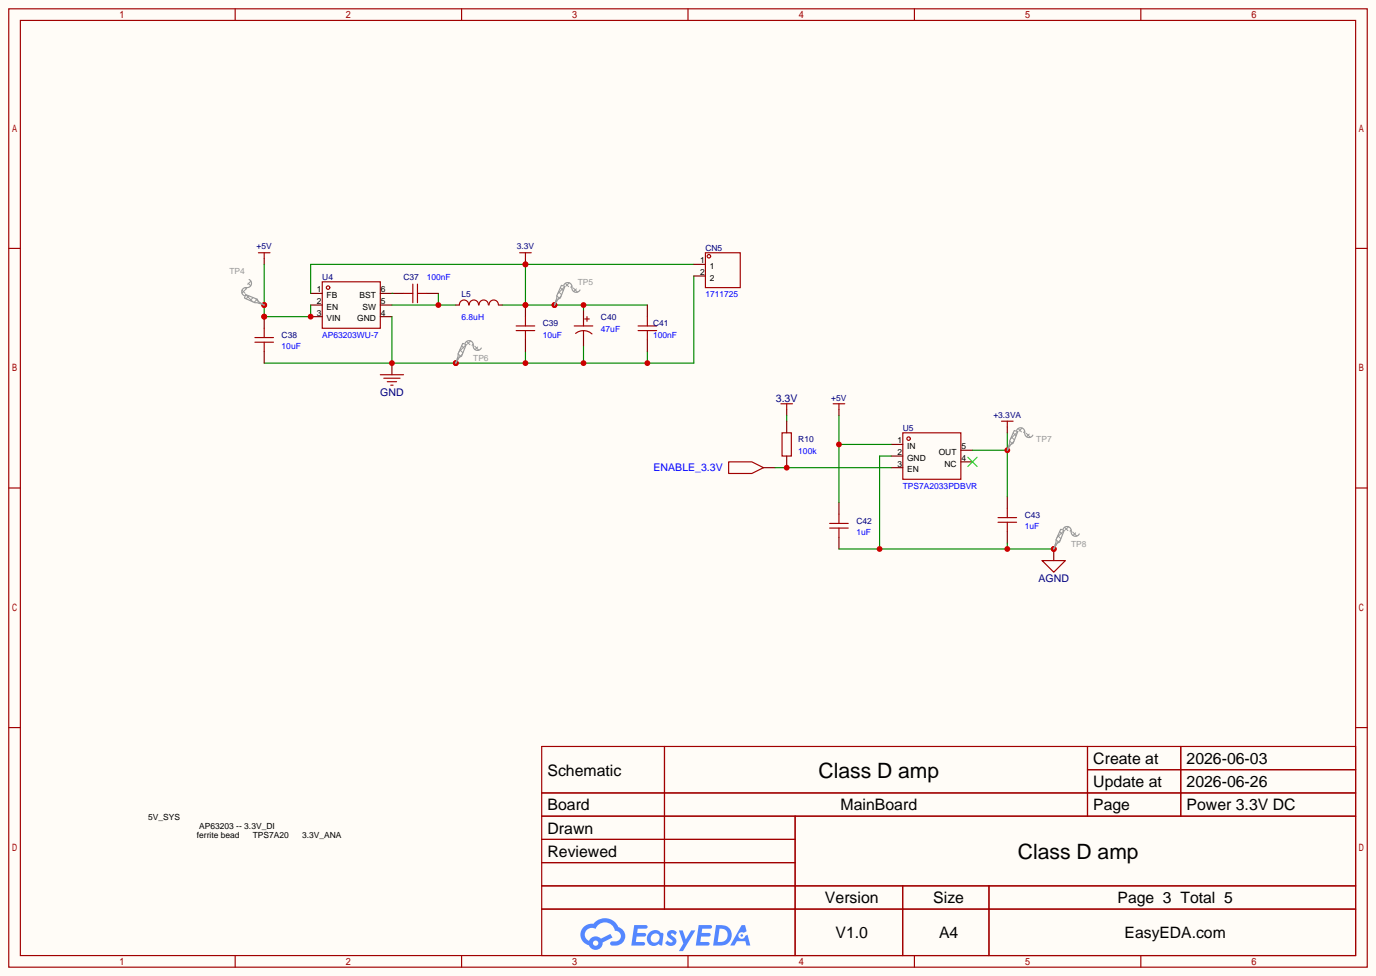
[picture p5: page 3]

Schematic | Class D amp | Create at | 2026-06-03

Update at | 2026-06-26

Board | MainBoard | Page | Power 3.3V DC
Drawn | | Class D amp
Reviewed

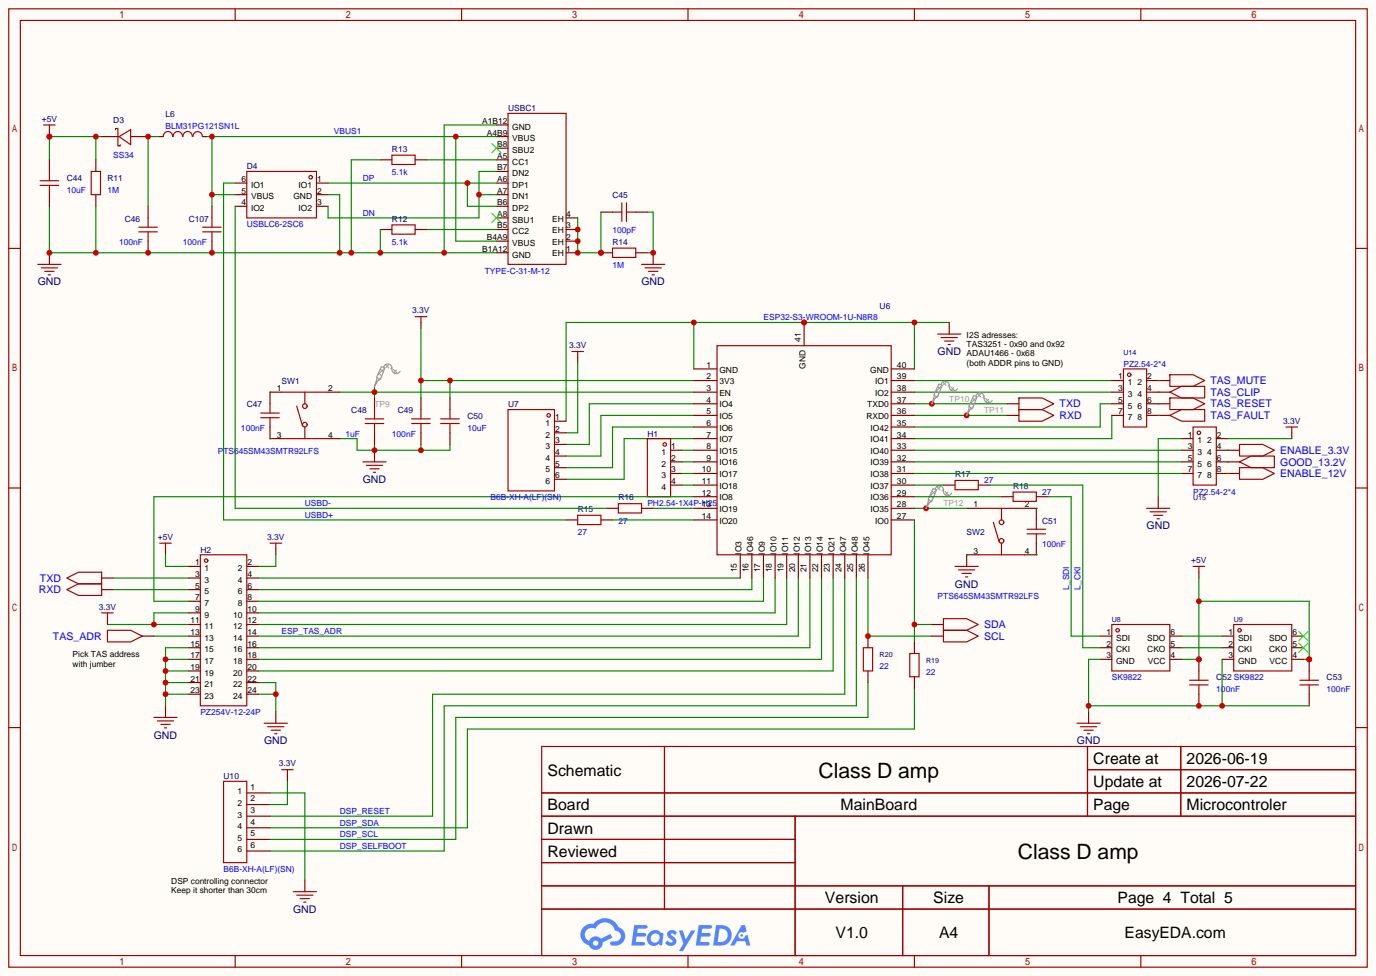
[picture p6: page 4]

Schematic | Class D amp | Create at | 2026-06-19

Update at | 2026-07-22

Board | MainBoard | Page | Microcontroler
Drawn | | Class D amp
Reviewed

DSP controlling connector
Keep it shorter than 30cm

## SDA SCL

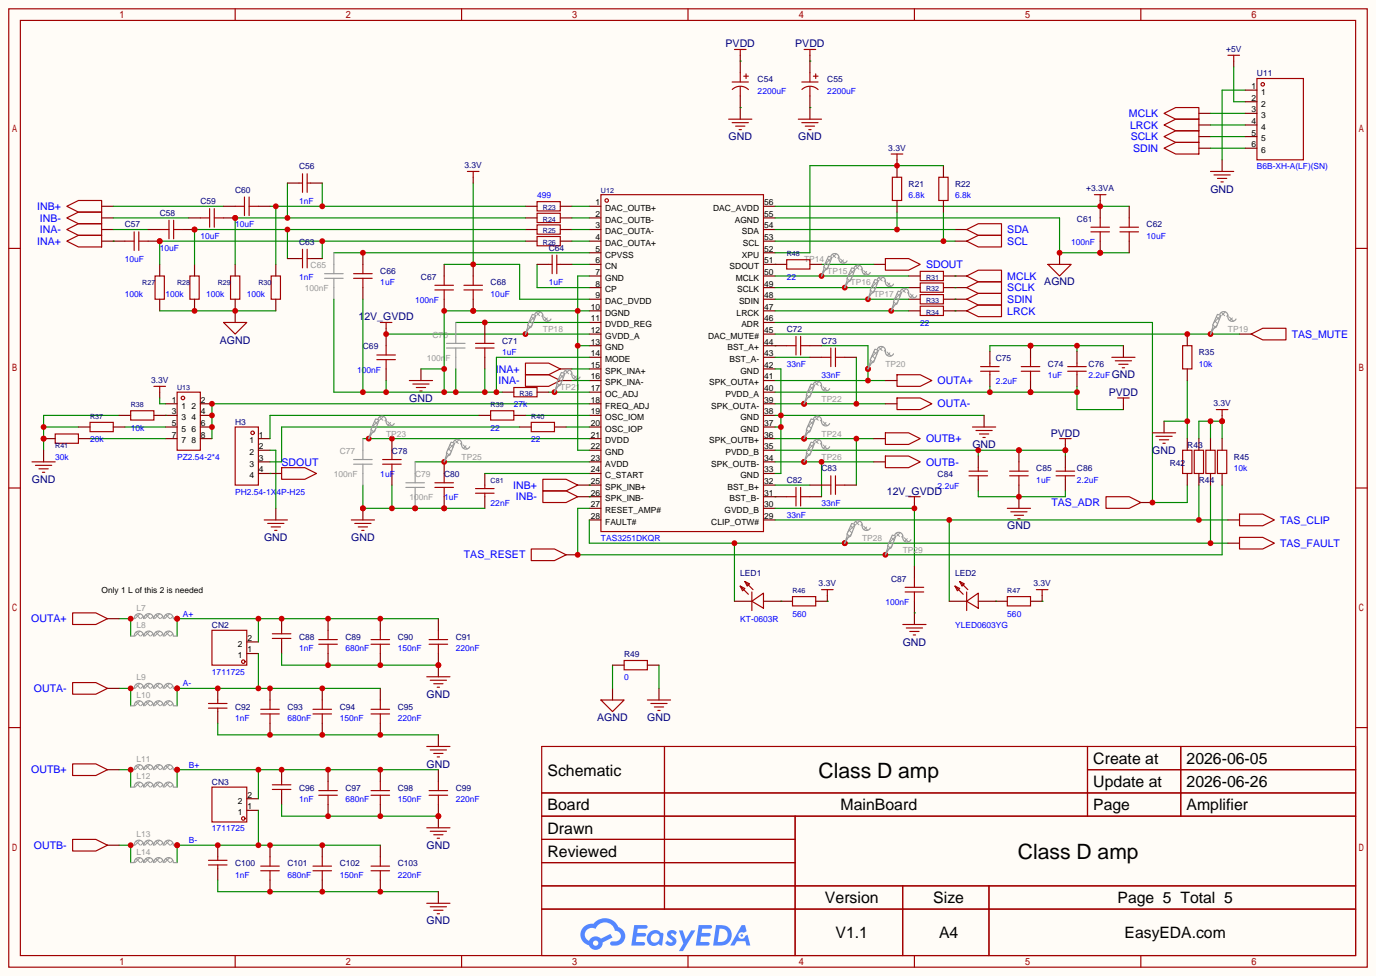
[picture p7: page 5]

Only 1 L of this 2 is needed

Schematic | Class D amp | Create at | 2026-06-05

Update at | 2026-06-26

Board | MainBoard | Page | Amplifier
Drawn | | Class D amp
Reviewed

Version | Size | Page 5 Total 5
V1.1 | A4 | EasyEDA.com

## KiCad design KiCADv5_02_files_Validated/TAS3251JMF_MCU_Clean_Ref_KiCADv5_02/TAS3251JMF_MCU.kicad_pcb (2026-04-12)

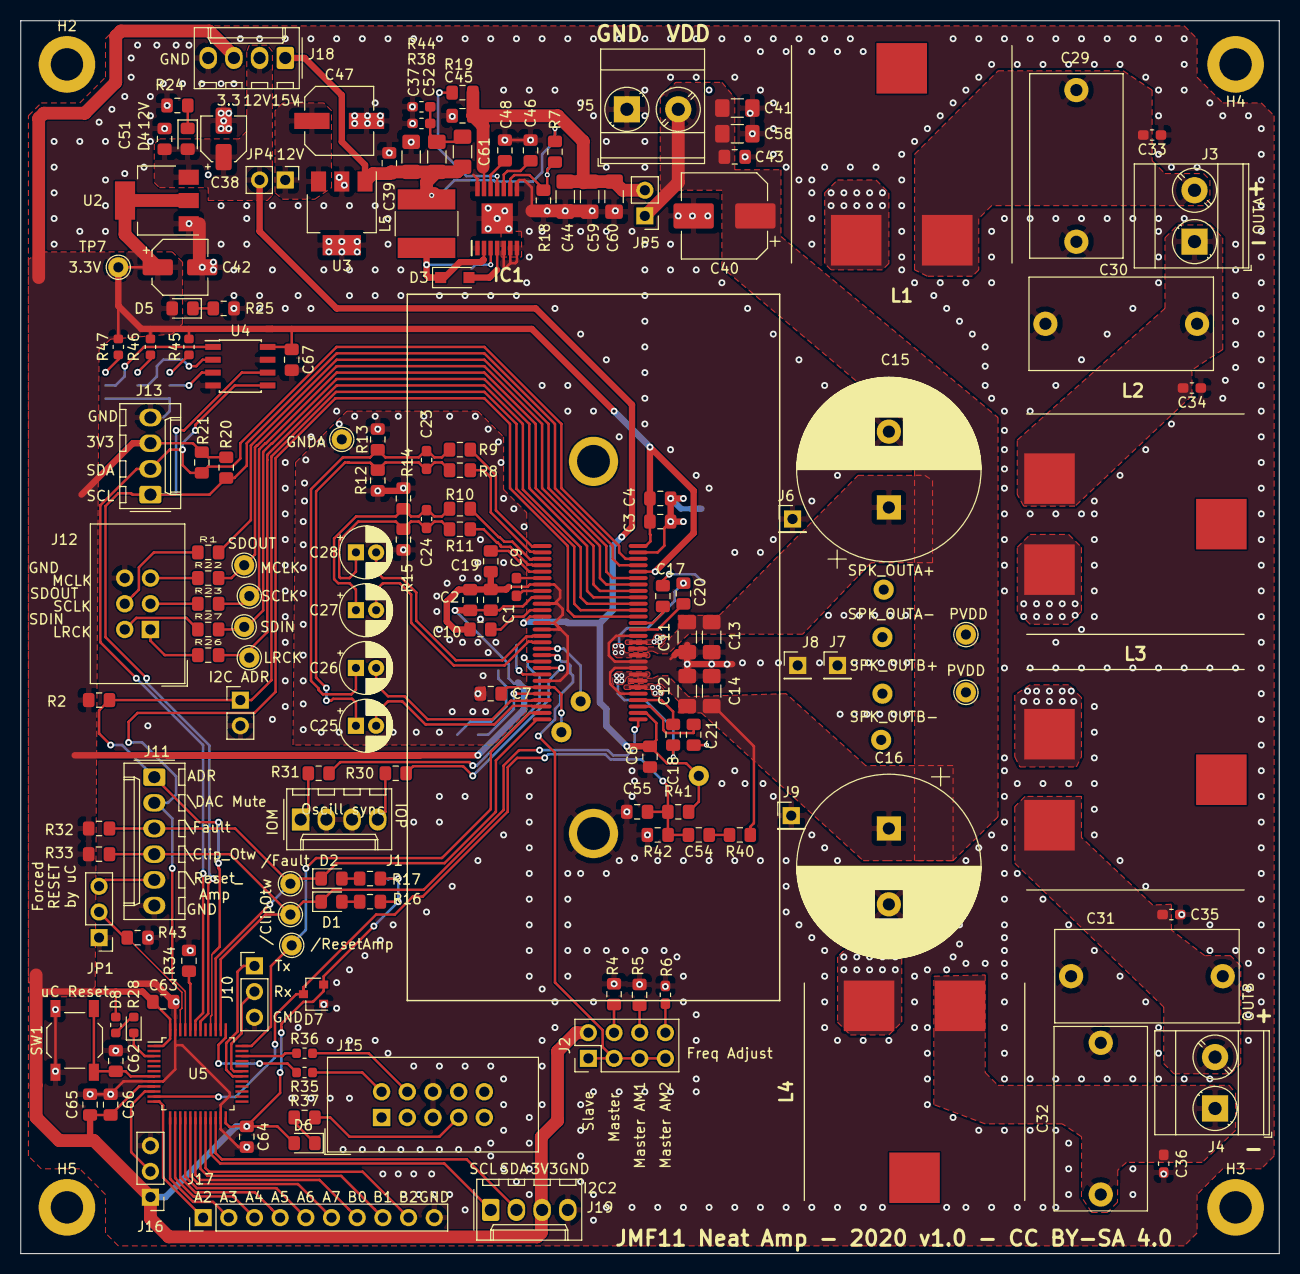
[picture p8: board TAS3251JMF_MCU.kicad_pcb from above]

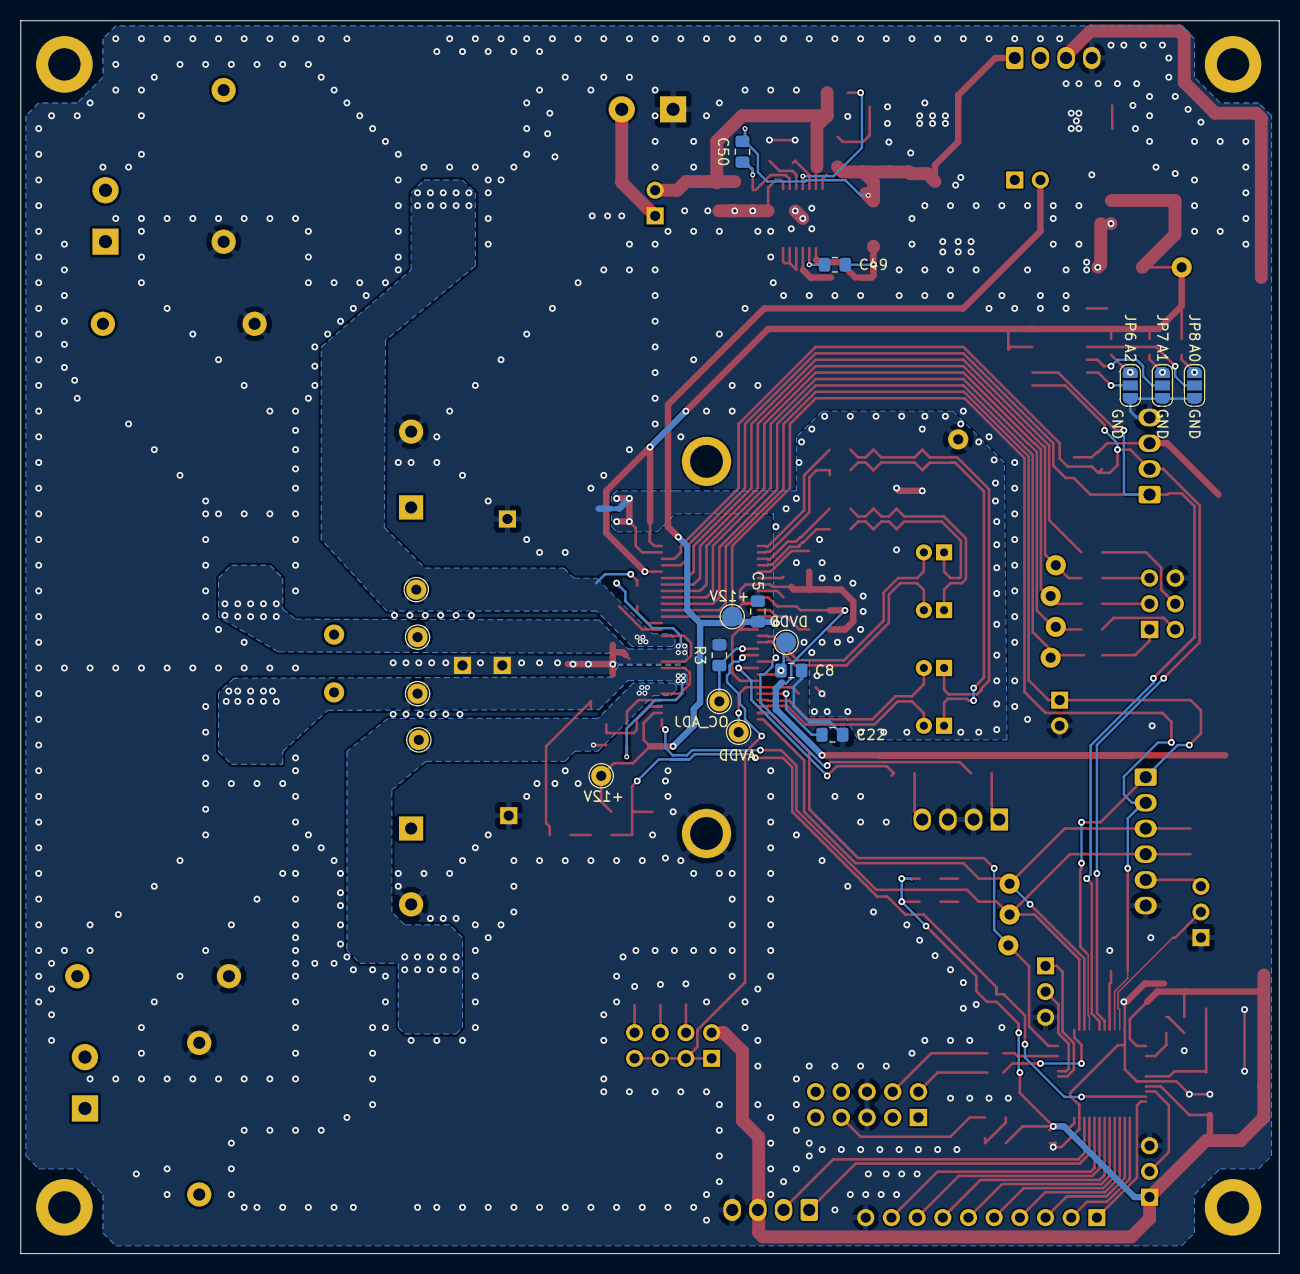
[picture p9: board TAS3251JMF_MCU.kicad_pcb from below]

Board: 2 copper layers, 124.5 x 121.9 mm, 180 parts (19 on the bottom side), 111 nets.

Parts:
C1, C4: 10µF; C_0805_2012Metric_Pad1.15x1.40mm_HandSolder
C2, C3, C5, C6, C10, C45, C49, C51, C62, C63, C64, C67: 0.1µF; C_0805_2012Metric_Pad1.15x1.40mm_HandSolder
C7, C8, C19, C54, C55, C66: 1µF; C_0805_2012Metric_Pad1.15x1.40mm_HandSolder
C9: 2.2µF; C_0603_1608Metric_Pad1.05x0.95mm_HandSolder
C11, C12, C13, C14, C41, C44, C58, C59, C60: 2.2µF; C_1206_3216Metric_Pad1.42x1.75mm_HandSolder
C15, C16: 2400µF; CP_Radial_D18.0mm_P7.50mm
C17, C18, C20, C21: 0.033µF; C_0805_2012Metric_Pad1.15x1.40mm_HandSolder
C22: 0.047µF; C_0805_2012Metric_Pad1.15x1.40mm_HandSolder
C23, C24, C33, C34, C35, C36: 1000pF; C_0603_1608Metric_Pad1.05x0.95mm_HandSolder
C25, C26, C27, C28: 10µF; CP_Radial_D5.0mm_P2.00mm
C29, C30, C31, C32: 0.68µF; C_Rect_L18.0mm_W9.0mm_P15.00mm_FKS3_FKP3
C37, C52, C61: 4.7µF; C_1206_3216Metric_Pad1.42x1.75mm_HandSolder
C38: 10µF; CP_Elec_4x5.8
C39, C48: 0.47µF; C_0805_2012Metric_Pad1.15x1.40mm_HandSolder
C40: 47µF; CP_Elec_8x6.2
C42: 100µF; CP_Elec_5x5.8
C43, C65: 0.01µF; C_0805_2012Metric_Pad1.15x1.40mm_HandSolder
C46, C50: 4700pF; C_0805_2012Metric_Pad1.15x1.40mm_HandSolder
C47: 47µF; CP_Elec_6.3x5.8
D1: Orange; LED_0805_2012Metric_Pad1.15x1.40mm_HandSolder
D2: Red; LED_0805_2012Metric_Pad1.15x1.40mm_HandSolder
D3: D_Schottky; D_SOD-123F
D4, D5, D6: Green; LED_0805_2012Metric_Pad1.15x1.40mm_HandSolder
D7: D_Schottky_x2_Serial_AKC; SOT-23
D8: Green; LED_0603_1608Metric
H2, H3, H4, H5: MountingHole; MountingHole_3.2mm_M3_DIN965_Pad
HS1: Heatsink; Advanced_ATS078036036-TI1OP-1099-C1-R1
IC1: LM5010MHX; SOP65P640X110-15N
J1: Oscill sync; Molex_KK-254_AE-6410-04A_1x04_P2.54mm_Vertical
J2: Freq Adjust; PinHeader_2x04_P2.54mm_Vertical
J3: OUTA; TerminalBlock_Phoenix_MKDS-3-2-5.08_1x02_P5.08mm_Horizontal
J4: OUTB; TerminalBlock_Phoenix_MKDS-3-2-5.08_1x02_P5.08mm_Horizontal
J5: PVDD; TerminalBlock_Phoenix_MKDS-3-2-5.08_1x02_P5.08mm_Horizontal
J6, J7, J8, J9: Conn_01x01_Male; PinHeader_1x01_P2.54mm_Vertical
J10, J16: Conn_01x03; PinHeader_1x03_P2.54mm_Vertical
J11: Conn_01x06; Molex_KK-254_AE-6410-06A_1x06_P2.54mm_Vertical
J12: Conn_02x03_Odd_Even; IDC-Header_2x03_P2.54mm_Vertical
J13, J18, J19: Conn_01x04; Molex_KK-254_AE-6410-04A_1x04_P2.54mm_Vertical
J15: Conn_02x05; IDC-Header_2x05_P2.54mm_Vertical
J17: Conn_01x10; PinHeader_1x10_P2.54mm_Vertical
JP1: AMP RESET Jumper; PinHeader_1x03_P2.54mm_Vertical
JP2, JP4, JP5: Jumper_2_Bridged; PinHeader_1x02_P2.54mm_Vertical
JP6, JP7, JP8: SolderJumper_3_Open; SolderJumper-3_P1.3mm_Open_RoundedPad1.0x1.5mm_NumberLabels
L1, L2, L3, L4: 10 µH; WE-HCF_201322
L5: 150µH; L_Wuerth_74404064151_Handsolder
NT1: Net-Tie_2; NetTie-2_SMD_Pad0.5mm
R1, R22, R23, R26, R27, R30, R31: 22; R_0805_2012Metric_Pad1.15x1.40mm_HandSolder
R2, R4, R32, R33, R34: 10.0k; R_0805_2012Metric_Pad1.15x1.40mm_HandSolder
R3: 22.0k; R_0805_2012Metric_Pad1.15x1.40mm_HandSolder
R5, R43: 20.0k; R_0805_2012Metric_Pad1.15x1.40mm_HandSolder
R6: 30.0k; R_0603_1608Metric_Pad1.05x0.95mm_HandSolder
R7: 5.1k; R_0805_2012Metric_Pad1.15x1.40mm_HandSolder
R8, R9, R10, R11, R25: 499; R_0805_2012Metric_Pad1.15x1.40mm_HandSolder
R12, R13, R14, R15, R40: 100k; R_0805_2012Metric_Pad1.15x1.40mm_HandSolder
R16, R17, R37: 560; R_0805_2012Metric_Pad1.15x1.40mm_HandSolder
R18: 1.02k; R_0805_2012Metric_Pad1.15x1.40mm_HandSolder
R19: 365k; R_0805_2012Metric_Pad1.15x1.40mm_HandSolder
R20, R21: 6.8k; R_0805_2012Metric_Pad1.15x1.40mm_HandSolder
R24: 1.50k; R_0805_2012Metric_Pad1.15x1.40mm_HandSolder
R28: 560; R_0603_1608Metric
R35, R36: 22; R_0603_1608Metric
R38: 0; R_0603_1608Metric_Pad1.05x0.95mm_HandSolder
R41: 12k; R_0805_2012Metric_Pad1.15x1.40mm_HandSolder
R42: 3.3k; R_0805_2012Metric_Pad1.15x1.40mm_HandSolder
R44: NoPOP; R_0603_1608Metric_Pad1.05x0.95mm_HandSolder
R45, R46, R47: 10.0k; R_0603_1608Metric
SW1: SW_Push; SW_SPST_TL3342
TP1: GND; TestPoint_THTPad_D2.0mm_Drill1.0mm
TP2: MCLK; TestPoint_THTPad_D2.0mm_Drill1.0mm
TP3: BCLK; TestPoint_THTPad_D2.0mm_Drill1.0mm
TP4: LRCK; TestPoint_THTPad_D2.0mm_Drill1.0mm
TP5: SDIN; TestPoint_THTPad_D2.0mm_Drill1.0mm
TP6: TP - Reset_Amp; TestPoint_THTPad_D2.0mm_Drill1.0mm
TP7: DAC-AVDD; TestPoint_THTPad_D2.0mm_Drill1.0mm
TP9: OC-ADJ; TestPoint_THTPad_D2.0mm_Drill1.0mm
TP10: GVDD_A; TestPoint_THTPad_D2.0mm_Drill1.0mm
TP11: GVDD_B; TestPoint_Pad_D2.0mm
TP12: AVDD; TestPoint_THTPad_D2.0mm_Drill1.0mm
TP13: DVDD; TestPoint_Pad_D2.0mm
TP14: PVDD_B; TestPoint_THTPad_D2.0mm_Drill1.0mm
TP15: PVDD_A; TestPoint_THTPad_D2.0mm_Drill1.0mm
TP16: OUTA+; TestPoint_THTPad_D2.0mm_Drill1.0mm
TP17: OUTA-; TestPoint_THTPad_D2.0mm_Drill1.0mm
TP18: OUTB+; TestPoint_THTPad_D2.0mm_Drill1.0mm
TP19: OUTB-; TestPoint_THTPad_D2.0mm_Drill1.0mm
TP20: CLIP_OTW; TestPoint_THTPad_D2.0mm_Drill1.0mm
TP21: FAULT; TestPoint_THTPad_D2.0mm_Drill1.0mm
U1: TAS3251; DKQ0056A
U2: AMS1117-3.3; SOT-223-3_TabPin2
U3: LM2940-12; SOT-223
U4: AT24C256C; SOIC-8_3.9x4.9mm_P1.27mm
U5: STM32F030C8Tx; LQFP-48_7x7mm_P0.5mm

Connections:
+3V3: C1.1, C2.1, C3.1, C4.1, C42.1, C63.1, C64.1, C65.1, C66.1, C67.1, D5.2, D6.2, D7.2, J2.2, J13.3, J16.1, J18.3, J19.3, R2.1, R16.2, R17.2, R20.2, R21.2, R28.1, R32.1, R33.1, R45.1, R46.1, R47.1, TP7.1, U1.9, U1.52, U1.56, U2.2, U4.8, U5.1, U5.9, U5.24, U5.48
+12V: C5.1, C6.1, C38.1, C51.2, D4.2, J18.2, JP4.2, R41.1, TP10.1, TP11.1, U1.12, U1.30, U2.3
+15V: C37.1, C39.1, C50.1, C52.1, C61.1, J18.1, L5.2, R7.1, U3.1
/TAS3251/ADR: J11.1, JP2.1, R2.2, U1.46, U5.40
/TAS3251/AVDD: C7.2, TP12.1, U1.23
/TAS3251/C_START: C22.1, U1.24
/TAS3251/DAC_OUTA+: R10.1, U1.3
/TAS3251/DAC_OUTA-: R11.1, U1.4
/TAS3251/DAC_OUTB+: R9.1, U1.1
/TAS3251/DAC_OUTB-: R8.1, U1.2
/TAS3251/DVDD: C8.2, TP13.1, U1.21
/TAS3251/FREQ_ADJ: J2.1, J2.3, J2.5, J2.7, U1.18
/TAS3251/GPIO_1: J17.1, U5.12
/TAS3251/GPIO_2: J17.2, U5.13
/TAS3251/GPIO_3: J17.3, U5.14
/TAS3251/GPIO_4: J17.4, U5.15
/TAS3251/GPIO_5: J17.5, U5.16
/TAS3251/GPIO_6: J17.6, U5.17
/TAS3251/GPIO_7: J17.7, U5.18
/TAS3251/GPIO_8: J17.8, U5.19
/TAS3251/GPIO_9: J17.9, U5.20
/TAS3251/I2C2_SCA: J19.2, U5.22
/TAS3251/I2C2_SCL: J19.1, U5.21
/TAS3251/INA+: C24.2, C28.1, R11.2, R15.2
/TAS3251/INA-: C24.1, C27.1, R10.2, R14.2
/TAS3251/INB+: C23.2, C26.1, R9.2, R13.2
/TAS3251/INB-: C23.1, C25.1, R8.2, R12.2
/TAS3251/LRCK-Conn: J12.1, R26.2
/TAS3251/MCLK: R22.1, TP2.1, U1.50
/TAS3251/MCLK-Conn: J12.5, R22.2
/TAS3251/OSC-IOM: R31.1, U1.19
/TAS3251/OSC-IOP: R30.1, U1.20
/TAS3251/OUTA+: C29.1, C33.2, J3.2, L1.2
/TAS3251/OUTA-: C30.1, C34.2, J3.1, L2.1
/TAS3251/OUTB+: C31.1, C35.2, J4.2, L3.2
/TAS3251/OUTB-: C32.1, C36.2, J4.1, L4.1
/TAS3251/SCL: J13.1, R20.1, U1.53, U4.6, U5.42
/TAS3251/SCLK: R23.1, TP3.1, U1.49
/TAS3251/SCLK-Conn: J12.3, R23.2
/TAS3251/SDA: J13.2, R21.1, U1.54, U4.5, U5.43
/TAS3251/SDIN: R27.1, TP5.1, U1.48
/TAS3251/SDIN-Conn: J12.2, R27.2
/TAS3251/SDOUT-Conn: J12.4, R1.1
/TAS3251/SPK_OUTA+: C17.1, L1.1, TP16.1, U1.41
/TAS3251/SPK_OUTA-: C20.1, L2.2, TP17.1, U1.39
/TAS3251/SPK_OUTB+: C18.1, L3.1, TP18.1, U1.36
/TAS3251/SPK_OUTB-: C21.1, L4.2, TP19.1, U1.34
/TAS3251/SWCLK: R35.1, U5.37
/TAS3251/SWDIO: R36.1, U5.34
/TAS3251/USART1_RX: J10.2, U5.31
/TAS3251/USART1_TX: J10.1, U5.30
/TAS3251/Volume: J16.2, U5.10
/TAS3251/\CLIP_OTW: D1.1, J11.4, R33.2, TP20.1, U1.29, U5.38
/TAS3251/\DAC_MUTE: J11.2, U1.45, U5.45
/TAS3251/\RESET-AMP: TP6.1, U1.27, U5.36
/TAS3251/\RESET-AMP-Conn: J11.5, JP1.3
GND: C1.2, C2.2, C5.2, C6.2, C8.1, C10.2, C11.1, C12.1, C13.1, C14.1, C15.2, C16.2, C19.1, C22.2, C29.2, C30.2, C31.2, C32.2, C33.1, C34.1, C35.1, C36.1, C37.2, C38.2, C39.2, C40.2, C41.1, C42.2, C43.2, C44.2, C45.2, C46.2, C47.2, C48.1, C51.1, C55.2, C58.2, C59.2, C60.2, C62.2, C63.2, C64.2, C65.2, C66.2, C67.2, D7.1, HS1.1, IC1.1, IC1.5, IC1.6, IC1.7, IC1.8, IC1.14, IC1.15, J1.2, J1.3, J5.1, J6.1, J7.1, J8.1, J9.1, J10.3, J11.6, J12.6, J13.4, J15.5, J15.6, J16.3, J17.10, J18.4, J19.4, JP1.1, JP2.2, JP6.1, JP7.1, JP8.1, NT1.1, R3.1, R4.1, R5.1, R6.1, R18.2, R24.2, R25.2, R34.2, R38.2, R42.2, R43.2, R44.2, SW1.1, U1.7, U1.10, U1.13, U1.14, U1.22, U1.33, U1.37, U1.38, U1.42, U2.1, U3.2, U3.4, U4.4, U4.7, U5.8, U5.23, U5.47
GNDA: C3.2, C4.2, C7.1, NT1.2, R12.1, R13.1, R14.1, R15.1, TP1.1, U1.55
unnamed: C9.1, U1.6
unnamed: C9.2, U1.8
unnamed: C10.1, U1.11
unnamed: C17.2, U1.44
unnamed: C18.2, U1.32
unnamed: C19.2, U1.5
unnamed: C20.2, U1.43
unnamed: C21.2, U1.31
unnamed: C44.1, C45.1, C59.1, C60.1, IC1.13, JP5.2, R19.2
unnamed: C46.1, IC1.10
unnamed: C47.1, JP4.1, U3.3
unnamed: C48.2, IC1.12
unnamed: C49.1, D3.1, IC1.2, L5.1
unnamed: C49.2, IC1.3
unnamed: C50.2, IC1.9, R7.2, R18.1
unnamed: C52.2, C61.2, R38.1, R44.1
unnamed: C54.1, R40.2
unnamed: C54.2, C55.1, D7.3, R41.2, R42.1, U5.11
unnamed: C62.1, SW1.2, U5.7
unnamed: D1.2, R16.1
unnamed: D2.2, R17.1
unnamed: D3.2, IC1.4
unnamed: D4.1, R24.1
unnamed: D5.1, R25.1
unnamed: D6.1, R37.1
unnamed: D8.1, U5.3
unnamed: D8.2, R28.2
unnamed: IC1.11, R19.1
unnamed: J1.1, R31.2
unnamed: J1.4, R30.2
unnamed: J2.4, R4.2
unnamed: J2.6, R5.2
unnamed: J2.8, R6.2
unnamed: J15.2, R35.2
unnamed: J15.4, R36.2
unnamed: J15.7, R37.2
unnamed: JP1.2, R43.1, U5.46
unnamed: JP6.2, U4.3
unnamed: JP6.3, R45.2
unnamed: JP7.2, U4.2
unnamed: JP7.3, R46.2
unnamed: JP8.2, U4.1
unnamed: JP8.3, R47.2
unnamed: R1.2, U1.51
unnamed: R3.2, TP9.1, U1.17
unnamed: R26.1, TP4.1, U1.47
unnamed: R34.1, U5.44
SPK_INA+: C28.2, U1.15
SPK_INA-: C27.2, U1.16
SPK_INB+: C26.2, U1.25
SPK_INB-: C25.2, U1.26
VDD: C11.2, C12.2, C13.2, C14.2, C15.1, C16.1, C40.1, C41.2, C43.1, C58.1, J5.2, JP5.1, R40.1, TP14.1, TP15.1, U1.35, U1.40
\FAULT: D2.1, J11.3, R32.2, TP21.1, U1.28, U5.39

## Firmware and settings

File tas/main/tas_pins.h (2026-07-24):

/**
 * @file tas_pins.h
 * @brief Raw ESP32-S3 GPIO/I2C pin assignments for the NeatAmpTAS3251 board.
 *
 * These constants are the single source of truth for the pin mapping
 * documented in the "ESP32-S3 Hardware IO" and "Potential DSP (ADAU1466)
 * Connectivity" tables in the top-level README.md of this firmware project.
 * They are consumed by tas::PowerSupplies, tas::Tas3251 and tas::Dsp; no
 * other file should hardcode a GPIO number.
 */
#ifndef TAS_PINS_H
#define TAS_PINS_H

#include "driver/gpio.h"
#include "driver/i2c_master.h"

/** @name Shared I2C control bus (TAS3251 + optional ADAU1466 registers) */
///@{
#define TAS_I2C_PORT I2C_NUM_0
#define TAS_I2C_FREQUENCY_HZ 400000

#define TAS_PIN_I2C_SDA GPIO_NUM_0
#define TAS_PIN_I2C_SCL GPIO_NUM_45
///@}

/** @name TAS3251 amplifier control/status lines */
///@{
#define TAS_PIN_AMP_RESET GPIO_NUM_42
#define TAS_PIN_DAC_MUTE GPIO_NUM_1
#define TAS_PIN_AMP_FAULT GPIO_NUM_41
#define TAS_PIN_AMP_CLIP_OTW GPIO_NUM_2
#define TAS_PIN_AMP_ADDRESS GPIO_NUM_12
///@}

/** @name Power sequencing lines (see PowerSupplies) */
///@{
#define TAS_PIN_GOOD_13V2 GPIO_NUM_39
#define TAS_PIN_ENABLE_12V GPIO_NUM_38
#define TAS_PIN_ENABLE_3V3_ANALOG GPIO_NUM_40
///@}

/** @name Optional ADAU1466 DSP control lines (connector U10) */
///@{
#define TAS_PIN_DSP_RESET GPIO_NUM_47
#define TAS_PIN_DSP_SELFBOOT GPIO_NUM_48
///@}

/**
 * @name Status LED chain (U8, U9 — SK9822, APA102-compatible clocked RGB)
 * U8 is first in the chain (data/clock in from the ESP32-S3), its CKO/SDO
 * feed U9's CKI/SDI. Both lines are ESP32-S3 outputs through 27 Ohm series
 * resistors (R17 on CKI, R18 on SDI, per Netlist_Class_D_amp_2026-07-23.enet).
 */
///@{
#define TAS_PIN_STATUS_LED_SDI GPIO_NUM_36
#define TAS_PIN_STATUS_LED_CKI GPIO_NUM_37
///@}

/**
 * @note I2S audio bus (MCLK/BCLK/LRCK/SDIN) is NOT currently wired to any
 * ESP32-S3 GPIO. Per Netlist_Class_D_amp_2026-07-23.enet (repository root),
 * connector U11 (the external DIR9001/DSP I2S header) only connects to the
 * TAS3251 (U12 pins 47-50) through 22 Ohm series resistors — the ESP32-S3
 * (U6) has no net in common with MCLK/LRCK/SCLK/SDIN on the current board
 * revision. tas::I2sBus therefore takes its pin assignment as a runtime
 * parameter rather than a macro defined here; do not add ESP32 I2S pin
 * macros to this file until a board revision actually routes them.
 */

#endif

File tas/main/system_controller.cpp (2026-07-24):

/**
 * @file system_controller.cpp
 * @brief SystemController implementation. See system_controller.hpp for the
 *        public API and tas/README.md for the state diagram this mirrors.
 */
#include "system_controller.hpp"

#include <cinttypes>

#include "esp_app_desc.h"
#include "esp_chip_info.h"
#include "esp_flash.h"
#include "esp_log.h"
#include "esp_mac.h"
#include "esp_system.h"
#include "freertos/FreeRTOS.h"
#include "freertos/task.h"

namespace tas {
namespace {
constexpr char kTag[] = "SystemController";

const char *resetReasonToString(esp_reset_reason_t reason)
{
    switch (reason) {
        case ESP_RST_POWERON:
            return "power-on";
        case ESP_RST_EXT:
            return "external pin";
        case ESP_RST_SW:
            return "software (esp_restart)";
        case ESP_RST_PANIC:
            return "panic/exception";
        case ESP_RST_INT_WDT:
            return "interrupt watchdog";
        case ESP_RST_TASK_WDT:
            return "task watchdog";
        case ESP_RST_WDT:
            return "other watchdog";
        case ESP_RST_DEEPSLEEP:
            return "deep sleep wakeup";
        case ESP_RST_BROWNOUT:
            return "brownout";
        case ESP_RST_SDIO:
            return "SDIO";
        case ESP_RST_USB:
            return "USB";
        case ESP_RST_JTAG:
            return "JTAG";
        case ESP_RST_EFUSE:
            return "efuse error";
        case ESP_RST_PWR_GLITCH:
            return "power glitch";
        case ESP_RST_CPU_LOCKUP:
            return "CPU lockup (double exception)";
        case ESP_RST_UNKNOWN:
        default:
            return "unknown";
    }
}

/**
 * @brief Log everything readily available about the running chip and
 *        firmware image, so a serial capture always identifies exactly
 *        what is on the board (target, revision, flash, firmware version,
 *        MAC, why it last reset) without needing a debugger attached.
 */
void logChipInfo()
{
    esp_chip_info_t chipInfo;
    esp_chip_info(&chipInfo);

    uint32_t flashSizeBytes = 0;
    esp_flash_get_size(nullptr, &flashSizeBytes);

    uint8_t mac[6] = {0};
    esp_read_mac(mac, ESP_MAC_WIFI_STA);

    const esp_app_desc_t *app = esp_app_get_description();

    ESP_LOGI(kTag, "Chip: %s, %d core(s), silicon revision v%d.%d, %s%s%s%sflash %" PRIu32 " MB (%s)",
             CONFIG_IDF_TARGET, chipInfo.cores, chipInfo.revision / 100, chipInfo.revision % 100,
             (chipInfo.features & CHIP_FEATURE_WIFI_BGN) ? "WiFi/" : "",
             (chipInfo.features & CHIP_FEATURE_BT) ? "BT/" : "",
             (chipInfo.features & CHIP_FEATURE_BLE) ? "BLE/" : "",
             (chipInfo.features & CHIP_FEATURE_IEEE802154) ? "802.15.4/" : "",
             flashSizeBytes / (1024 * 1024),
             (chipInfo.features & CHIP_FEATURE_EMB_FLASH) ? "embedded" : "external");
    ESP_LOGI(kTag, "MAC (WiFi STA): %02X:%02X:%02X:%02X:%02X:%02X", mac[0], mac[1], mac[2], mac[3], mac[4], mac[5]);
    ESP_LOGI(kTag, "Heap: %" PRIu32 " bytes free now, %" PRIu32 " bytes minimum free since boot",
             esp_get_free_heap_size(), esp_get_minimum_free_heap_size());
    ESP_LOGI(kTag, "Firmware: project \"%s\" v%s, built %s %s, ESP-IDF %s", app->project_name, app->version,
             app->date, app->time, app->idf_ver);
    ESP_LOGI(kTag, "Last reset reason: %s", resetReasonToString(esp_reset_reason()));
}

/**
 * @note Placeholder value suggested during architecture review, to let the
 *       13.2V->12V LDO chain and 3.3V analog rail settle before RESET_AMP
 *       is released. TODO: verify against the TAS3251 datasheet power-up
 *       timing spec — if isRail13V2Good() already guarantees the rail has
 *       settled, this fixed delay may be redundant and could be removed or
 *       shortened.
 */
constexpr uint32_t kPowerStabilizeDelayMs = 100;

/**
 * @note Placeholder value suggested during architecture review, inserted
 *       between enabling the 12V/3.3V analog rails and releasing RESET_AMP.
 *       TODO: verify against the TAS3251 datasheet minimum reset-to-supply
 *       or supply-to-reset-release timing before relying on it.
 */
constexpr uint32_t kPreResetReleaseDelayMs = 50;

/**
 * @note Conservative "low" volume, used both as the startup default and as
 *       the volume applied when a fault mutes the amp. Deliberately chosen
 *       independently of whether Tas3251::setVolumeDb()'s dB-to-register-code
 *       formula is correct (see its @warning) — a wrong-but-quiet result is
 *       safe, a wrong-and-loud one is not.
 */
constexpr float kLowVolumeDb = -60.0f;

constexpr uint32_t kMonitorLoopPeriodMs = 50;

/** @note How long the CLIP/OTW visual flash (LED index 1, U9) stays lit.
 *  Purely cosmetic — see SystemController::handleClipOtw(). */
constexpr uint32_t kClipFlashMs = 120;

/** @name Status LED colors (see SystemController::Status) */
///@{
constexpr RgbColor kColorBooting{0, 0, 255};
constexpr RgbColor kColorReady{0, 255, 0};
constexpr RgbColor kColorFault{255, 0, 0};
constexpr RgbColor kColorStartupFailed{255, 140, 0};
constexpr RgbColor kColorClipFlash{255, 180, 0};
constexpr RgbColor kColorOff{0, 0, 0};
///@}
} // namespace

esp_err_t SystemController::fail(esp_err_t err)
{
    status_ = Status::StartupFailed;
    statusLed_.setColor(0, kColorStartupFailed);
    return err;
}
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

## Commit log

2026-04-12 Opening with version 9.0.8 and saving
    [PowerSupplies.kicad_sch, PowerSupplies.sch, TAS3251.kicad_sch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]
2026-04-15 Adding Coilcraft XGL1712103 footprint
2026-04-16 Adding development placeholders. Moving uC SCH to separate sheet.
    [MA5172-AE.stp, PowerSupplies.kicad_sch, TAS3251.kicad_sch]
2026-04-16 Adding gitignore for kicad
2026-04-19 Separating SCHs
    [TAS3251.kicad_sch, TAS3251JMF_MCU.kicad_sch, microcontroler.kicad_sch]
2026-04-19 Adding new uC module
    [TAS3251JMF_MCU.kicad_sch, microcontroler.kicad_sch]
2026-04-20 adding components
    [PowerSupplies.kicad_sch, TAS3251.kicad_sch, TAS3251JMF_MCU.kicad_sch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]
2026-04-21 adding ESP32 schematic
    [untitled.kicad_sch]
2026-04-21 Minor changes
    [PowerSupplies.kicad_sch, untitled.kicad_sch]
2026-04-21 fixing names
    [TAS3251JMF_MCU.kicad_sch, microcontroler-new.kicad_sch]
2026-04-21 Adding signals to control for new uC
    [PowerSupplies.kicad_sch, TAS3251JMF_MCU.kicad_sch, microcontroler-new.kicad_sch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]
2026-04-21 minor fix to architecture
    [PowerSupplies.kicad_sch]
2026-04-22 modifying power supply architecture
    [PowerSupplies.kicad_sch]
2026-04-22 adding 3d shape for LMQ
    [LMQ66430R5RXBR.stp]
2026-04-23 Adding PS
    [PowerSupplies.kicad_sch]
2026-04-24 modified PSU
    [PowerSupplies.kicad_sch, microcontroler-new.kicad_sch]
2026-04-27 putting togather 12V Analog
2026-04-28 adding more PSU for 5 and 3.3V
2026-04-28 starting to add ESP32
2026-05-08 minor footprint fix
2026-05-11 minor component swap - ESP32
2026-05-12 adding DSP connector
2026-05-17 adding DSP dongle board
2026-05-22 fixing safety on power inputs. LMQ fixes.
2026-05-22 shortcircuiting AGND and GND
2026-05-23 Schematic V1.0 done
2026-05-27 more traces to PCB
2026-05-27 adding copper planes and fixing power section
2026-05-28 Final PCB V1.0 - ready for assembling
2026-05-29 increasing size of PCB due to PnP limitation
2026-05-29 fixing power-OR lines
2026-05-30 PCB fixes according to sch done
2026-05-30 adding components to PCB
2026-06-01 more fixes and PCB work
2026-06-01 more PCB work. Output pin adjusted.
2026-06-03 more work on PCB and some fixes in SCH
2026-06-04 more of PCB
2026-06-19 rerouting SCH and more routest to PCB
2026-06-20 ground planes and tuning
2026-06-21 adding more GND planes
2026-06-21 adding pull-up R to unconnected pin
2026-06-22 fixing holes, optimizing COG C at exit. More ground.
2026-06-22 more beautification to PCB
2026-06-24 moving a track in a copy. hopefully resolving issues with versions
2026-06-24 few traces made wider. Some PVDD impruvement
2026-06-27 BOM fixes, shape tuning. plastic box
2026-06-27 case and finalization. This commit was ORDERED.
2026-07-22 Fixing PCB issue with USBC connector
2026-07-23 Updating Readme with production details and fix relevant to the current version
2026-07-23 Adding ESP32 project core
2026-07-23 Adding initial project template for ESP32-S3 on board
2026-07-23 Adding pin connections of ESP to software includes.
2026-07-23 Adding PDF of the schematic
2026-07-24 updating Readme files with details from schematic (pcb). To have all properly documented.
2026-07-24 Adding initial implementation attempt - done by Claude. Also adding current netlist of the electonics.
2026-07-24 adding control of two featured LEDs on the board
2026-07-28 Adding initial implementation. Cleaning up old files not relevant to this stage of project.
2026-10-20 Document ESP-IDF install via eim CLI; SDK now uses ESP-IDF 6.1
    README: add command-line eim install steps (Python 3.10-3.13 requirement,
    libexec/bin PATH fix) and switch the documented ESP-IDF version to 6.1,
    verified with an esp32s3 build. Ignore the generated eim_config.toml.
2026-10-30 Stop using ESP32-S3 IO35/IO36/IO37 (Octal PSRAM pins on N8R8)
    On ESP32-S3-WROOM-1U-N8R8, module pins 28/29/30 (IO35/IO36/IO37) are wired
    internally to the Octal PSRAM. HW V1.0/V1.1 used them for SW2+C51 and the
    SK9822 status LED data/clock, which corrupts PSRAM and crashes firmware.
    Firmware:
    - Move status LED SDI/CKI to IO8/IO9 (H2 pins 7/8) - matches proposed HW
    V1.2 and the V1.0/V1.1 rework.
    - Switch PSRAM to Octal mode (N8R8); Quad mode fails PSRAM init.
    - Add static_assert in tas_pins.h rejecting IO35-IO37 in Octal mode.
    Docs:
    - README: V1.2 proposed HW change, full ESP32-S3 module pinout table
    (V1.0/V1.1 vs V1.2), SW config summary, status warning.
    - tas/README: reserved-pins and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
2026-10-30 HW V1.2 schematic: move LEDs to IO8/IO9, SW2 to IO10, free PSRAM pins
    Schematic (EasyEDA Pro V3.2.209) and netlist Netlist_Class_D_amp_2026-10-30.enet:
    - ESP32-S3 module pins 28/29/30 (IO35-37) left unconnected.
    - U8 SDI <- R18 <- IO8, U8 CKI <- R17 <- IO9.
    - SW2 + C51 + TP12 moved to IO10 with new R51 10k pull-up.
    - IO8/IO9/IO10 removed from H2 (pins 7, 8, 10 now NC).
    Docs: align V1.2 tables with the actual netlist, record EasyEDA V3.2.209,
    correct I2C pull-up value (6.8k R21/R22, not 4.7k).
2026-11-06 Docs: V1.2 layout status and V1.0/V1.1 -> V1.2 rework guide
    - README: V1.2 is now schematic + PCB layout done (DRC clean), not produced;
    outline/connectors/heatsink unchanged. Note that Schematic.pdf and the 3D
    render are V1.0/V1.1. Remove stray heatsink line, move "Next versions"
    out of the EasyEDA setup section, fix Windows library symlink path.
    - tas/README: rename checklist to V1.0/V1.1 rework checklist, add optional
    SW2 -> IO10 rework (trace cut + 10k pull-up), add a table of differences
    that remain between a reworked V1.0/V1.1 and V1.2, note that L_SDI/L_CKI
    are unnamed nets in the V1.2 netlist.
2026-11-06 HW V1.2: silkscreen revision, re-exported schematic and 3D renders
    - EasyEDA project: PCB silkscreen revision text set to V 1.2.
    - Schematic.pdf and Pictures/PCB_3D.png re-exported from V1.2.
    - New Pictures/PCB_3D_TOP.png top-view render, shown in README.
    - README release notes updated accordingly.
2026-11-10 Adding migration to KiCADv10 of schematic with shapes and nets from old project.

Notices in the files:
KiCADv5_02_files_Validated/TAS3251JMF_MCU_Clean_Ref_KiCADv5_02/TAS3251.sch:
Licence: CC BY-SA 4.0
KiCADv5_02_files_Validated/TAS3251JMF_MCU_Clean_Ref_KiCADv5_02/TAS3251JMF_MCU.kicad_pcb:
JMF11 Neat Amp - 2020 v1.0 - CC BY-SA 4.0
